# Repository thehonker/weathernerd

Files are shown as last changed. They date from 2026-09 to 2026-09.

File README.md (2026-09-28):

# WeatherNerd




Low-power, long-duration weather stations built around the [WindNerd Core](https://github.com/windnerd-labs/Windnerd-Core) anemometer and ESP32-C6 dataloggers.

## What is this?

Two station variants sharing the same wind sensor and datalogger platform:

### Remote Station (v1)

A battery-powered, 6-month-unattended weather station for remote deployment. No grid power, no WiFi infrastructure, no maintenance visits. Deploy in fall, retrieve in spring.

- **Wind:** WindNerd Core (STM32G031F8) with custom firmware — STOP mode sleep (~5 µA), woken on demand by ESP32-C6 every 5s via GPIO interrupt. Wind speed via rotor pulse counting, direction via TMAG5273 magnetic angle sensor.
- **Datalogger:** ESP32-C6 SuperMini, running **ESP-IDF v6.1** (not Arduino — the LP RISC-V coprocessor requires ESP-IDF's `ulp_embed_binary` build system). LP core handles the 5s wind sampling loop while the main core sleeps (~7 µA deep sleep). Main core wakes every 1 min for temp/RH/pressure, rain ADC, and SD card flush.
- **Sensors:** BME280 (temp/RH/pressure, I2C), DS3231 RTC (±2 ppm, I2C), DIY piezo disdrometer (ADC, rain rate).
- **Storage:** 8 GB industrial microSD via SPI. Two daily CSV files: `YYYY-MM-DD-wind.csv` (5s samples) and `YYYY-MM-DD-env.csv` (1 min samples). ~168 MB for 6 months.
- **Power:** 2× ER34615 Li-SOCl2 D-cells (38 Ah, -55°C rated). Total system draw ~0.55 mA (16× battery headroom over 6 months). Battery lasts years — power is a non-issue.
- **Uplink:** SIM7080G Cat-M1 modem on AT&T LTE-M network. MQTT uplink every 30 min with buffered data. Daily GPS fix via SIM7080G GNSS syncs the DS3231 RTC, eliminating long-term drift. PSM sleep (~3 µA module) between uploads.
- **Retrieval:** Press CON button on the enclosure → ESP32-C6 powers on OLED display + starts WiFi 6 soft-AP. Connect with phone/laptop, browse and download CSV files. Rotary encoder + OLED for on-device UI. LTE-M uplink provides live data during deployment — WiFi is for full bulk download on physical retrieval.
- **Antenna:** Directional Yagi (700–2700 MHz) aimed at nearest AT&T tower for LTE-M. Passive GNSS patch antenna (25×25mm) for daily GPS RTC sync.
- **Cost:** ~$214-283 total BOM.

### Home Station (future)

A wall-powered variant for permanent installation at home. Same WindNerd Core + ESP32-C6 platform, but always-on WiFi with Prometheus-style metrics exposure:

- `/metrics` endpoint scraped by a Prometheus instance
- Wind speed, direction, temperature, RH, pressure, rain rate as gauge metrics
- DS3231 RTC for timestamp accuracy
- No battery, no SD card — data lives in Prometheus
- OLED + encoder UI always available
- Optional: push to a remote station's data archive for cross-site comparison

Design docs for the home station will be added when we start that phase. The remote station firmware and hardware are the priority — the home station reuses the same components and most of the same firmware.

## Repo layout

```none
weathernerd/
├── README.md              ← you are here
├── LICENSE
├── .github/workflows/
│   └── build-windnerd-stm32g031f8.yml  ← CI/CD for STM32 firmware
└── local-storage/
    ├── notes/
    │   ├── hardware-design.md   ← pin allocation, wiring, BOM, component selection
    │   ├── power-budget.md      ← current draw analysis, battery sizing
    │   ├── storage-budget.md    ← data volume, SD card selection, file strategy
    │   └── lte-uplink.md        ← LTE-M modem options, antenna, SIM, power impact
    └── firmware/
        ├── windnerd-stm32g031f8/  ← custom WindNerd Core firmware (⚠️ WIP, untested)
        │   ├── README.md           ← firmware docs, build & flash instructions
        │   ├── build.sh            ← build locally (Docker)
        │   ├── flash.sh            ← flash via ST-Link (Docker)
        │   ├── src/src.ino         ← firmware source
        │   ├── lib/Windnerd-Core/  ← git submodule
        │   └── build-env/          ← Dockerfile + compile/flash scripts
        └── esp32c6-supermini/     ← ESP32-C6 datalogger firmware (ESP-IDF, ✅ compiles)
            ├── README.md           ← firmware docs, build & flash instructions
            ├── CMakeLists.txt      ← ESP-IDF project root
            ├── sdkconfig.defaults  ← LP core, FAT/SD, WiFi AP, BT disabled
            ├── partitions.csv      ← nvs + phy + 3 MB factory
            ├── build.sh            ← build locally (Docker)
            ├── flash.sh            ← flash via USB serial (Docker)
            ├── main/
            │   ├── CMakeLists.txt  ← ulp_embed_binary() for LP core
            │   ├── main.c          ← main core firmware
            │   ├── storage.h/.c    ← SDSPI + CSV writing (wind + env)
            │   ├── i2c_bus.h/.c    ← shared I2C bus (GPIO6/7)
            │   ├── ds3231.h/.c     ← DS3231 RTC driver
            │   ├── bme280.h/.c     ← BME280 driver + compensation
            │   ├── wifi.h/.c         ← WiFi AP + HTTP server (files, clock, format, reboot, halt)
            │   ├── oled.h/.c       ← SH1106 OLED driver (128×64, text)
            │   ├── oled_font.h     ← 8×8 ASCII font
            │   ├── input.h/.c      ← EC11 encoder + CON/BAK/PSH buttons
            │   ├── ui.h/.c         ← Interactive menu UI (6 items)
            │   └── lp_core/main.c  ← LP core firmware
            └── build-env/          ← Dockerfile (espressif/idf:release-v6.1)
```

## Design docs

Start with [hardware-design.md](local-storage/notes/hardware-design.md) for the full system overview, pin allocation, and BOM.
[power-budget.md](local-storage/notes/power-budget.md) covers current draw and battery life.
[storage-budget.md](local-storage/notes/storage-budget.md) covers data volumes and SD card selection.
[lte-uplink.md](local-storage/notes/lte-uplink.md) covers LTE-M modem selection, antenna, SIM, and power budget impact.

## Firmware

### WindNerd Core (STM32G031F8) — ⚠️ WIP, untested - compiles, sensors implemented

Custom firmware replacing the factory WindNerd Core firmware. Drops power from ~0.6 mA (SLEEP mode) to ~0.04 mA (STOP mode) by sleeping until the ESP32-C6 triggers a read via GPIO interrupt. Uses the TMAG5273 driver directly from the WindNerd Core library — the `WN_Core` class is not used.

- **Status:** Written, compiles clean (62% flash, 25% RAM), not yet tested on hardware
- **Build:** `./build.sh` (Docker, no host tooling needed) → `build/src.ino.bin`
- **Flash:** `./flash.sh` (ST-Link V2, openocd in Docker) or `./flash.sh --ci` (download from GitHub releases)
- **CI/CD:** Auto-builds on push to main, publishes env image to GHCR + GitHub release with firmware binaries
- **Details:** [windnerd-stm32g031f8/README.md](local-storage/firmware/windnerd-stm32g031f8/README.md)

### ESP32-C6 SuperMini — ⚠️ WIP, untested — compiles, all features implemented

ESP32-C6 datalogger firmware built with **ESP-IDF v6.1**. The LP RISC-V coprocessor handles the 5s wind sampling loop (WindNerd trigger + UART RX) while the main core sleeps. Main core wakes every 1 min for sensors + SD card flush. Interactive UI (OLED + encoder + buttons) triggered by CON button press — provides live data, file browser, WiFi portal, clock sync, format SD, reboot, sleep, and halt.

- **Status:** All firmware modules written and compiling clean. Full data flow implemented: LP core samples wind every 5s → main core flushes to SD every 1 min. Interactive UI with 8 menu items. WiFi portal with file browser, clock sync, format SD, reboot, halt. Only hardware testing remains.
- **Binary:** 1.15 MB (37% of 3 MB factory partition — WiFi stack adds ~800 KB)
- **Build:** `./build.sh` (Docker, no host toolchain needed) → `build/esp32c6_weathernerd.bin`
- **Flash:** `./flash.sh` (USB serial, esptool in Docker) or `./flash.sh --ci` (download from GitHub releases)
- **CI/CD:** Auto-builds on push, publishes env image to GHCR + GitHub release with firmware binaries
- **Details:** [esp32c6-supermini/README.md](local-storage/firmware/esp32c6-supermini/README.md)

**Why ESP-IDF, not Arduino?** The ESP32-C6's LP RISC-V coprocessor is the whole reason we chose the C6 over the C3. Arduino-esp32 does not support LP core programming — no `ulp_embed_binary()` build pipeline, no LP core API exposure. ESP-IDF is the official framework for LP core development.

## Key design decisions

- **WindNerd custom firmware** — factory firmware draws 0.6 mA. Custom STOP mode + on-demand sampling drops it to ~0.04 mA. 7× total system power reduction.
- **ESP32-C6 over ESP32-C3** — the C6's LP RISC-V coprocessor handles the 5s sampling loop while the main core sleeps. The C3 has no LP core, so the main core would wake every 5s, roughly doubling power consumption. This required switching from Arduino to ESP-IDF — Arduino-esp32 doesn't support LP core programming.
- **No solar** — at 0.55 mA average, the battery alone has 16× headroom over 6 months. Solar adds complexity and failure modes for zero benefit.
- **Two data streams** — wind+rain at 5s (LP core) and temp/RH/pressure at 1 min (main core). Separate daily CSV files. Temp changes slowly; 1 min is plenty.
- **CON button + OLED** — the station sleeps with zero UI. A momentary button (CON) wakes the main core via GPIO interrupt, firmware powers on the OLED via MOSFET (GPIO5), and starts a WiFi AP for data retrieval. Zero power when off. BAK button at top-level menu returns to low-power mode. 60s inactivity timeout as backup. A future "Halt" option (full system stop, power cycle to resume) may be added to both the OLED menu and WiFi portal.
- **SPI over SDIO for SD card** — GPIO18–23 are the ESP32-C6's native SDIO peripheral, but 4-bit SDIO needs 6 pins and would eat GPIO20/21 (encoder) and GPIO22/23 (CON/BAK buttons). SPI mode uses 4 pins and the data rate is trivial (~838 KB/day, 70-byte appends once per minute). The SD card is asleep 55s out of every 60s — SDIO's speed advantage is irrelevant. The saved pins keep the encoder and buttons on safe, non-strapping GPIO.
- **DIY piezo disdrometer** — no moving parts, $2 in parts, logs raw ADC peaks. Calibrate later against a reference gauge. v1 has no op-amp (simplest); v2 adds OPA376 if drizzle sensitivity is needed.
- **SIM7080G LTE-M uplink** — Cat-M1 on AT&T (the only carrier with coverage at the deployment site). PSM sleep at ~3 µA between 30-min MQTT uploads. LC filter on VBAT handles Cat-M1 TX spikes from the high-internal-resistance Li-SOCl2 battery. Daily GPS fix via the modem's GNSS receiver syncs the DS3231 RTC, eliminating ±5 min drift over 6 months. NB-IoT is dead on AT&T (sunset Q1 2025) — Cat-M1 is the only viable low-power IoT option.

## License

`AGPL-3.0-or-later`. See [LICENSE](LICENSE).

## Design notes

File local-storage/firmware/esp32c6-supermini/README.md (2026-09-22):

# esp32c6-supermini — WeatherNerd ESP32-C6 Firmware



Firmware for the ESP32-C6 SuperMini datalogger — the main controller of the WeatherNerd remote station.

Built with **ESP-IDF v6.1** (not Arduino). The ESP32-C6's LP RISC-V coprocessor requires ESP-IDF's `ulp_embed_binary` build system — Arduino-esp32 does not support LP core programming.

## Architecture

```
┌─────────────────────────────────────────────────┐
│  ESP32-C6 SuperMini                              │
│                                                  │
│  ┌──────────┐   shared RTC    ┌──────────────┐   │
│  │ LP Core  │───memory───────▶│  Main Core   │   │
│  │ (RISC-V) │                 │  (RISC-V)    │   │
│  │          │                 │              │   │
│  │ 5s loop: │                 │ 1 min wake:  │   │
│  │ trigger  │                 │ read BME280  │   │
│  │ WindNerd │                 │ read DS3231  │   │
│  │ read UART │                │ read rain ADC │   │
│  │ store    │                 │ flush to SD   │   │
│  │ sample   │                 │ deep sleep    │   │
│  │ halt     │                 │              │   │
│  └──────────┘                 └──────────────┘   │
│       │                              │           │
│       │ GPIO1 (trigger)              │ GPIO22    │
│       │ GPIO4 (LP_UART RX)           │ (WiFi SW) │
│       ▼                              ▼           │
│  ┌──────────┐                 ┌──────────────┐   │
│  │ WindNerd │                 │ WiFi AP +    │   │
│  │ Core     │                 │ OLED UI      │   │
│  │ (STM32)  │                 │ (on demand)  │   │
│  └──────────┘                 └──────────────┘   │
└─────────────────────────────────────────────────┘
```

### LP Core (ULP coprocessor)

Wakes every 5 seconds via LP timer while main core sleeps:
1. Pulse GPIO1 high for 10ms → wakes WindNerd Core (STM32G031F8) from STOP mode
2. Read UART response on LP_UART (GPIO4, 9600 baud) — `WNI,<speed>,<dir>\n`
3. Parse and store wind sample in shared RTC memory buffer
4. After 12 samples (1 minute), wake the main core
5. Halt — LP timer wakes again in 5s

### Main Core

**Cold boot:** Initialize LP UART (9600 baud, RX=GPIO4), load LP core binary, configure GPIO22 wakeup, enter deep sleep.

**LP core wakeup (every 1 min):** Read BME280 (temp/RH/pressure, I2C), read DS3231 (timestamp, I2C), read rain ADC (HP ADC, GPIO0), flush 12 wind samples + env data to SD card (SPI), enter deep sleep.

**GPIO22 wakeup (CON button):** Power on OLED via MOSFET (GPIO5), start WiFi 6 soft-AP, serve CSV files via HTTP, OLED + rotary encoder UI. Returns to low-power mode on 60s timeout, menu action, or BAK button at top level.

### Known limitation: rain ADC resolution

The ESP32-C6 LP core does **not** have an LP ADC peripheral (`SOC_LP_ADC_SUPPORTED` is not defined). Rain ADC sampling moved to the main core's 1-minute wake cycle using the HP ADC. Rain resolution is 1 min instead of 5s — acceptable for v1 since rain rate doesn't change much in 60 seconds.

## Project structure

```
esp32c6-supermini/
├── CMakeLists.txt           ← ESP-IDF project root
├── sdkconfig.defaults       ← LP core, FAT/SD, WiFi AP enabled, BT disabled, 4 MB flash
├── partitions.csv           ← nvs (16K) + phy (4K) + factory (3 MB)
├── build.sh                 ← Docker build helper
├── flash.sh                 ← Docker flash helper (--ci mode)
├── .gitignore
├── main/
│   ├── CMakeLists.txt       ← idf_component_register + ulp_embed_binary()
│   ├── main.c               ← main core firmware (deep sleep, wakeup dispatch)
│   ├── storage.h / .c       ← SDSPI init, FAT mount, CSV file writing (wind + env)
│   ├── i2c_bus.h / .c       ← shared I2C bus (GPIO6/7, 100 kHz)
│   ├── ds3231.h / .c        ← DS3231 RTC driver (probe, get/set time, temp)
│   ├── bme280.h / .c        ← BME280 driver (probe, init, forced read, compensation)
│   ├── wifi.h / .c           ← WiFi soft-AP + HTTP server (files, clock sync, format, reboot, halt)
│   ├── oled.h / .c          ← SH1106 OLED driver (I2C, 128×64, text rendering)
│   ├── oled_font.h          ← 8×8 ASCII font (96 chars, 768 bytes)
│   ├── input.h / .c         ← EC11 encoder + CON/BAK/PSH buttons (GPIO ISR + debounce)
│   ├── ui.h / .c            ← Interactive menu UI (live data, files, WiFi, clock, sleep, halt)
│   └── lp_core/
│       └── main.c           ← LP core firmware (5s wind sampling loop)
└── build-env/
    ├── Dockerfile           ← espressif/idf:release-v6.1 base
    ├── compile.sh           ← container: idf.py set-target + build
    └── flash.sh             ← container: idf.py flash
```

## Hardware

- **Board:** ESP32-C6 SuperMini (ESP32-C6FH4)
- **Flash:** 4 MB QIO
- **LP core peripherals used:** LP IO (GPIO1 trigger), LP UART (GPIO4 RX, 9600 baud)
- **Main core peripherals:** I2C (BME280 + DS3231 + OLED on GPIO6/GPIO7), SPI (microSD on GPIO2/3/18/19), ADC (GPIO0 rain), GPIO5 (OLED MOSFET gate), GPIO14/20/21 (encoder TRA/TRB/PSH), GPIO22 (CON button), GPIO23 (BAK button)

See [hardware-design.md](../../notes/hardware-design.md) for full pin allocation and wiring.

## Dependencies

- **ESP-IDF v6.1** (bundled in Docker image — no host install needed)
- Docker (for containerized build/flash)
- USB-C cable (for flashing)

## Building locally

### Compile

```bash
cd local-storage/firmware/esp32c6-supermini
./build.sh
```

Pulls the prebuilt env image from GHCR and compiles the firmware. Output:

```
build/esp32c6_weathernerd.bin            ← flashable application binary
build/esp32c6_weathernerd.elf            ← debug symbols
build/bootloader/bootloader.bin          ← ESP32-C6 bootloader
build/partition_table/partition-table.bin ← partition table
```

To use a locally built image instead of GHCR:

```bash
docker build -t esp32c6-build ./build-env
ESP32C6_BUILD_IMAGE=esp32c6-build ./build.sh
```

### Flash

Connect ESP32-C6 SuperMini via USB-C, then:

```bash
./flash.sh                # flash locally built binary
./flash.sh --ci           # download latest CI release and flash that
./flash.sh --ci <sha>     # download release for a specific commit and flash
```

Override the serial port if auto-detection fails:

```bash
ESP32_PORT=/dev/ttyACM1 ./flash.sh
```

## CI/CD

GitHub Actions workflow: [`.github/workflows/build-esp32c6-supermini.yml`](../../../.github/workflows/build-esp32c6-supermini.yml)

**Triggers:** push to `main` or PR touching `local-storage/firmware/esp32c6-supermini/**`, plus manual dispatch.

**What it does:**
1. Builds the Docker env image and pushes it to `ghcr.io/thehonker/weathnerd-esp32c6-supermini-env` (tagged `:latest` and `:sha`). Image push happens only on push to `main`.
2. Compiles the firmware using the image (`idf.py set-target esp32c6 && idf.py build`).
3. Uploads `esp32c6_weathernerd.bin`, `esp32c6_weathernerd.elf`, `bootloader.bin`, and `partition-table.bin` as workflow artifacts (90-day retention).
4. On push to `main`: creates a GitHub release tagged `esp32c6-supermini-<sha>` with the binaries as downloadable assets.

**Env image:** `ghcr.io/thehonker/weathnerd-esp32c6-supermini-env:latest` — based on `espressif/idf:release-v6.1` (ESP-IDF v6.1 + RISC-V toolchain + esptool). Reusable for local builds:

```bash
docker pull ghcr.io/thehonker/weathnerd-esp32c6-supermini-env:latest
docker run --rm -v "$(pwd):/project" -w /project -u $(id -u) -e HOME=/tmp \
  ghcr.io/thehonker/weathnerd-esp32c6-supermini-env:latest /usr/local/bin/compile.sh
```

## Implementation status

| Component | Status |
|---|---|
| ESP-IDF project + LP core build | ✅ Compiles clean |
| LP core: WindNerd trigger (GPIO1) | ✅ Written |
| LP core: UART RX + parse | ✅ Written |
| LP core: sample buffer + main wakeup | ✅ Written |
| Main core: deep sleep + wakeup dispatch | ✅ Written |
| Main core: LP UART init | ✅ Written |
| Main core: I2C bus (shared) | ✅ Written |
| Main core: DS3231 RTC (I2C) | ✅ Written |
| Main core: BME280 sensor (I2C) | ✅ Written |
| Main core: rain ADC reads (HP ADC) | ✅ Written |
| Main core: SD card logging (SPI) | ✅ Written |
| Main core: env CSV writing (temp/RH/press) | ✅ Written |
| WiFi retrieval mode (soft-AP + HTTP) | ✅ Written |
| Clock sync from browser | ✅ Written |
| File browser + download | ✅ Written |
| OLED driver (SH1106, I2C) | ✅ Written |
| Encoder + button input (GPIO ISR) | ✅ Written |
| Interactive menu UI (6 items) | ✅ Written |
| OLED power gating (MOSFET on GPIO5) | ✅ Written |
| Halt option (full system stop) | ✅ Written |
| Wind samples → SD card (ulp_ variable access) | ✅ Written |

## Why ESP-IDF, not Arduino?

The ESP32-C6's LP RISC-V coprocessor is the whole reason we chose the C6 over the C3. Arduino-esp32 (3.3.12) does not support LP core programming — there's no build pipeline for `ulp_embed_binary()`, no `ulp_lp_core_load_binary()` / `ulp_lp_core_run()` API exposure, and no Kconfig support for `CONFIG_ULP_COPROC_TYPE_LP_CORE`. The feature has been requested ([arduino-esp32#9721](https://github.com/espressif/arduino-esp32/issues/9721)) since May 2024 with no progress.

ESP-IDF is the official framework for LP core development. The build system (`ulp_embed_binary` / `ulp_add_project`), Kconfig options, and LP core APIs (`ulp_lp_core.h`, `ulp_lp_core_uart.h`, `ulp_lp_core_gpio.h`) are all first-class. The Docker build pattern still works — just `espressif/idf:release-v6.1` instead of arduino-cli.

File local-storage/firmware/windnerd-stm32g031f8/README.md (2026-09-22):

# windnerd-stm32g031f8 — Custom WindNerd Core Firmware



Custom firmware for the [WindNerd Core](https://github.com/windnerd-labs/Windnerd-Core) board (STM32G031F8Px), replacing the factory firmware for ESP32-C6 triggered on-demand sampling.

## Why custom firmware?

The factory firmware is designed for standalone operation — it runs a 10 Hz timer (TIM3) that drives 3-second sampling windows, outputs `WNI`/`WNA` messages on UART, and enters SLEEP mode between samples. Current draw: ~0.6 mA in low power mode.

Our station doesn't need continuous sampling. The ESP32-C6 LP core triggers a read every 5 seconds. Between triggers, the WindNerd Core has nothing to do. STOP mode (~5 µA) drops power consumption by 120× — from 0.6 mA to 0.04 mA.

| | Factory firmware | This firmware |
|---|---|---|
| Sleep mode | SLEEP (~0.6 mA) | STOP (~5 µA) |
| Sampling trigger | TIM3 timer (10 Hz) | ESP32-C6 GPIO (EXTI) |
| Sample interval | 3 s (fixed) | 5 s (configurable, set by ESP32-C6) |
| Output | `WNI` + `WNA` messages | `WNI` only (on demand) |
| TMAG5273 | Read every 100-500 ms | Read only on trigger |
| LEDs | Active (speed + north) | Off (not initialized) |
| Power | ~0.6 mA | ~0.04 mA (estimated) |

## How it works

```
                    ESP32-C6 GPIO1 (trigger)
                           │ RISING edge
                           ▼
    ┌─────────────────────────────────────┐
    │  STM32G031F8 in STOP mode (~5 µA)   │
    │                                     │
    │  EXTI wakes CPU                     │
    │  → restore 8 MHz clock              │
    │  → read pulse count (reset to 0)    │
    │  → read TMAG5273 angle (I2C)        │
    │  → compute speed = pulses × 1.31 / 5│
    │  → UART TX2: "WNI,<speed>,<dir>\n"   │
    │  → return to STOP mode              │
    └─────────────────────────────────────┘
```

Rotor pulses (reed switch) increment a counter via EXTI. This works in STOP mode — the EXTI interrupt briefly wakes the CPU, the ISR increments the counter, and the CPU returns to STOP. The ESP32-C6 doesn't need to know about individual pulses; it just triggers every 5 seconds and gets the accumulated count.

## Output format

```
WNI,<speed_mps>,<direction_deg>
```

- `speed_mps`: wind speed in m/s, one decimal place (e.g. `3.2`)
- `direction_deg`: wind direction 0–359 degrees, or `0` if TMAG5273 read failed

Example: `WNI,3.2,247`

Same `WNI` format as factory firmware. No `WNA` (averaged) messages — averaging is done on the ESP32-C6 side from the 5s samples.

## Dependencies

- [WindNerd Core library](https://github.com/windnerd-labs/Windnerd-Core) — only for `Windnerd_TMAG5273.h/.cpp` and `Windnerd_I2C.h/.cpp` (TMAG5273 driver + I2C wrapper). The `WN_Core` class is **not** used. Included as a git submodule at `lib/Windnerd-Core/`.
- [stm32duino](https://github.com/stm32duino) 3.0.0 board package
- Docker (for containerized build/flash)

## Building locally

### Prerequisites

- Docker installed and running
- ST-Link V2 dongle (for flashing)
- Clone with submodules:

```bash
git clone --recursive <repo-url>
# or if already cloned:
git submodule update --init
```

### Compile

```bash
cd local-storage/firmware/windnerd-stm32g031f8
./build.sh
```

This pulls the prebuilt env image from GHCR and compiles the firmware. Output:

```
build/src.ino.bin   ← flashable binary (ST-Link SWD)
build/src.ino.elf    ← debug symbols
```

To use a locally built image instead of the GHCR one:

```bash
docker build -t windnerd-build ./build-env
WINDNERD_BUILD_IMAGE=windnerd-build ./build.sh
```

### Flash

Connect ST-Link V2 (CLK, DIO, RST, GND) to the WindNerd Core board, then:

```bash
./flash.sh                # flash locally built binary
./flash.sh --ci           # download latest CI release and flash that
./flash.sh --ci <sha>     # download release for a specific commit and flash
```

This passes USB through to the container, which runs openocd to flash via ST-Link SWD. No host-side tooling required — openocd is baked into the Docker image. The `--ci` mode downloads prebuilt firmware from GitHub releases using `curl` (no `gh` CLI needed).

Same `WINDNERD_BUILD_IMAGE` override works for `flash.sh`.

### Build without Docker (Arduino IDE)

If you prefer the Arduino IDE:

1. Follow the [WindNerd Core programming guide](https://github.com/windnerd-labs/Windnerd-Core/blob/main/docs/PROGRAM.md) to install STM32CubeProgrammer and stm32duino.
2. Install the WindNerd Core library into your Arduino `libraries/` folder (symlink or copy from `lib/Windnerd-Core/`).
3. Open `src/src.ino` in Arduino IDE.
4. Board: **Generic STM32G031F8Px**
5. Upload method: **STM32CubeProgrammer (SWD)** via ST-Link V2
6. Upload

## Pin assignments

| Pin | Function | Notes |
|---|---|---|
| PA25 | Rotor pulse input | Reed switch, EXTI RISING |
| PA22 | I2C SCL | TMAG5273 |
| PA23 | I2C SDA | TMAG5273 |
| PA0 | ESP32-C6 trigger | EXTI RISING, INPUT_PULLDOWN, expansion header |
| USART2 TX2 | UART output | 9600 baud, expansion header, to ESP32-C6 GPIO4 |

**Expansion header pinout:**

```
VCC
GND
PA6
PA5
PA4
PA3
TX2  (USART2 TX — UART output to ESP32-C6)
PA1
PA0  (ESP32-C6 trigger input)
3V3
TX   (bootloader)
RX   (bootloader)
GND
```

PA0 is confirmed on the header. If PA0 is needed for something else, PA1/PA3/PA4/PA5/PA6 are also available — all are EXTI-capable. Update `TRIGGER_PIN` in `src/src.ino`.

## Configuration

All configuration is in `src/src.ino`:

| Constant | Default | Description |
|---|---|---|
| `SAMPLE_INTERVAL_SEC` | 5 | Seconds between ESP32-C6 triggers. Must match ESP32-C6 LP core loop. |
| `HZ_TO_MS` | 1.31 | Rotor calibration. Standard WindNerd rotor = 1.31 m/s per Hz. |
| `UART_BAUD` | 9600 | Must match ESP32-C6 UART RX config. |

If the ESP32-C6 sample interval changes, update `SAMPLE_INTERVAL_SEC` and reflash. The STM32 uses this constant for speed calculation since `millis()`/`micros()` are unreliable after STOP mode (SysTick stops).

## STOP mode notes

- **SRAM retained** — `pulse_count` and all variables survive STOP mode
- **SysTick stopped** — `millis()` and `micros()` don't work after wakeup until `SystemClock_Config()` restores the clock
- **TIM3 stopped** — we don't use the WindNerd Core's timer-driven sampling
- **EXTI works** — rotor pulse ISR and trigger ISR both fire in STOP mode
- **I2C works after wakeup** — TMAG5273 read happens after clock restore
- **Clock restore** — STOP mode resets SYSCLK to HSI 16 MHz; `SystemClock_Config()` restores 8 MHz (HSI/2)

## Power estimate

| State | Current | Duration | Per-5s avg |
|---|---|---|---|
| STOP mode | ~5 µA | ~4.99 s | 4.99 µA |
| Wake + read + UART | ~3 mA | ~10 ms | 6 µA |
| **Average** | | | **~11 µA (~0.011 mA)** |

Factory firmware low power mode: ~600 µA. This firmware: ~11 µA. **55× reduction.**

Actual current needs to be measured on the physical board. The TMAG5273 sleep current (<1 µA) and I2C bus pull-ups may add a few µA.

## CI/CD

GitHub Actions workflow: [`.github/workflows/build-windnerd-stm32g031f8.yml`](../../../.github/workflows/build-windnerd-stm32g031f8.yml)

**Triggers:** push to `main` or PR touching `local-storage/firmware/windnerd-stm32g031f8/**`, plus manual dispatch.

**What it does:**
1. Builds the Docker env image and pushes it to `ghcr.io/thehonker/weathnerd-windnerd-stm32g031f8-env` (tagged `:latest` and `:sha`). Image push happens only on push to `main`.
2. Compiles the firmware using the image.
3. Uploads `src.ino.bin` and `src.ino.elf` as workflow artifacts (90-day retention).
4. On push to `main`: creates a GitHub release tagged `windnerd-stm32g031f8-<sha>` with the `.bin` and `.elf` as downloadable assets.

On PRs, the image builds but isn't pushed — firmware still compiles and artifacts are available for review. On `main`, the env image, workflow artifacts, and a GitHub release are all published.

**Env image:** `ghcr.io/thehonker/weathnerd-windnerd-stm32g031f8-env:latest` — Ubuntu 24.04 + arduino-cli 1.5.1 + stm32duino 3.0.0 + openocd. Reusable for local builds if you don't want to build the image yourself:

```bash
docker pull ghcr.io/thehonker/weathnerd-windnerd-stm32g031f8-env:latest
docker run --rm -v "$(pwd):/firmware" ghcr.io/thehonker/weathnerd-windnerd-stm32g031f8-env:latest /usr/local/bin/compile.sh
```

**Releases:** Firmware binaries are published as GitHub releases at `https://github.com/thehonker/weathernerd/releases`. Download with `curl` or use `./flash.sh --ci`.

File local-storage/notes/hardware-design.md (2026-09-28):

# Remote Wind Monitoring Station — Hardware Design

**Date:** 2026-09-22
**Author:** Coilette (for goos)
**Status:** Draft
**Related:** [power-budget.md](power-budget.md), [storage-budget.md](storage-budget.md)

---

## System Overview

```
  2× ER34615 Li-SOCl2 D-cell (3.6V, 38 Ah total)
       │
       ├──────────────────────────┐ (raw 3.6V)
       │                          │
  ┌────┴─────┐               SIM7080G VBAT
  │ HT7333   │ 3.3V LDO      (LTE-M modem, bulk cap for TX)
  └────┬─────┘ (~1 µA Iq)
       │ 3.3V rail
  ┌────┼──────┬───────┬───────┬───────┬───────┬───────┐
  ▼    ▼      ▼       ▼       ▼       ▼       ▼       ▼
WindNerd ESP32  BME280 DS3231 SD card Piezo  SIM7080G OLED
 Core    C6                            rain   (VCC)   (via
(STM32G0)                                (ADC)         MOSFET)
  │      │
  │      ├─ GPIO1  → trigger → WindNerd
  │      ├─ GPIO4  ← UART RX  ← WindNerd TX2 (9600 baud)
  │      ├─ GPIO0  ← ADC      ← Piezo rain
  │      ├─ GPIO6/7 → I2C → BME280 (0x76) + DS3231 (0x68) + OLED (0x3C) + MCP23008 (0x20)
  │      ├─ GPIO2/3/18/19 → SPI → SD card
  │      ├─ GPIO14 ← MCP23008 INT (encoder + buttons via I2C expander)
  │      ├─ GPIO5  → MOSFET gate → OLED VCC (power gate, firmware-controlled)
  │      ├─ GPIO16/17 → UART0 → SIM7080G (LTE-M uplink)
  │      ├─ GPIO15 → DTR → SIM7080G (PSM sleep/wake control)
  │      ├─ GPIO9  → PWR → SIM7080G (power key, pulse to on/off)
  │      ├─ GPIO20/22/23 → FREE (spare GPIO)
  │      └─ WiFi 6 soft-AP → phone/laptop (data retrieval)
```

**LP core** (5s loop): trigger WindNerd → read UART → buffer in RTC memory
**Main core** (1 min wake): read BME280 + DS3231 + rain ADC → flush buffered data to SD → return to deep sleep
**Main core** (30 min wake): wake SIM7080G from PSM via DTR → MQTT upload buffered data → modem back to PSM → deep sleep
**Main core** (daily): wake SIM7080G → enable GNSS → GPS fix → sync DS3231 RTC → disable GNSS → modem back to PSM → deep sleep
**On demand** (CON button press via MCP23008): wake main core → power on OLED via MOSFET → start WiFi AP → serve CSV files + clock sync → return to low-power mode on timeout or menu action

---

## Netlist

Every net on the platform. Sorted by signal name.

| Net | From | To | Notes |
|-----|---|----|---|
| **3V3** | HT7333 OUT | ESP32-C6 3V3, BME280 VCC, DS3231 VCC, SD VCC, OLED VCC (via Q2), WindNerd VCC, piezo GND ref | Main 3.3V rail |
| **GND** | HT7333 GND | ESP32-C6 GND, BME280 GND, DS3231 GND, SD GND, OLED GND, WindNerd GND, piezo GND, Q1 source, Q2 source, R2 bottom | Common ground |
| **VBAT** | ER34615 + (2 cells parallel) | HT7333 IN | 3.6V nominal, 19 Ah per cell, 38 Ah total |
| **VBAT_GND** | ER34615 − | HT7333 GND | |
| **WIND_TX** | WindNerd TX2 (yellow wire) | ESP32-C6 GPIO4 (LP_UART_RXD) | 9600 baud, 10kΩ pull-up on GPIO4 |
| **WIND_TRIG** | ESP32-C6 GPIO1 (LP core) | WindNerd trigger input | LP core toggles every 5s to wake WindNerd |
| **I2C_SDA** | ESP32-C6 GPIO6 | BME280 SDA, DS3231 SDA, OLED SDA | Shared bus, 0x76 + 0x68 + 0x3C |
| **I2C_SCL** | ESP32-C6 GPIO7 | BME280 SCL, DS3231 SCL, OLED SCL | Shared bus |
| **SPI_SCK** | ESP32-C6 GPIO2 | SD SCK | 10kΩ pull-down (idle low) |
| **SPI_CS** | ESP32-C6 GPIO3 | SD CS | 10kΩ pull-up (idle high) |
| **SPI_MOSI** | ESP32-C6 GPIO18 | SD MOSI | |
| **SPI_MISO** | ESP32-C6 GPIO19 | SD MISO | |
| **RAIN_ADC** | Piezo peak-hold C2 (+) | ESP32-C6 GPIO0 (ADC1_CH0) | Via 10kΩ series resistor R1 |
| **RAIN_RST** | ESP32-C6 GPIO8 | Q1 (2N7002) gate | HIGH 5ms pulse discharges C2. 10kΩ pulldown R2 to GND. |
| **OLED_PWR** | Q2 (AO3401) drain | OLED VCC | P-channel MOSFET switches VCC to OLED |
| **OLED_GATE** | ESP32-C6 GPIO5 | Q2 (AO3401) gate | LOW = OLED on, HIGH = OLED off. 10kΩ pull-up to 3V3. |
| **ENC_A** | EC11 encoder A | MCP23008 GP0 | Rotary encoder clock phase A (via I2C expander) |
| **ENC_B** | EC11 encoder B | MCP23008 GP1 | Rotary encoder data phase B (via I2C expander) |
| **ENC_PSH** | EC11 encoder push | MCP23008 GP2 | Encoder push button, internal pull-up (via I2C expander) |
| **CON_BTN** | CON button → GND | MCP23008 GP3 | Momentary, internal pull-up. UI confirm. INT wakes ESP32 on falling edge. |
| **BAK_BTN** | BAK button → GND | MCP23008 GP4 | Momentary, internal pull-up. UI back / enter sleep. (via I2C expander) |
| **EXP_INT** | MCP23008 INT | ESP32-C6 GPIO14 | Interrupt from I2C expander — wakes ESP32 on any pin change |
| **I2C_SDA** | ESP32-C6 GPIO6 | BME280 SDA, DS3231 SDA, OLED SDA, MCP23008 SDA | Shared bus, 0x76 + 0x68 + 0x3C + 0x20 |
| **I2C_SCL** | ESP32-C6 GPIO7 | BME280 SCL, DS3231 SCL, OLED SCL, MCP23008 SCL | Shared bus |
| **PIEZO+** | Piezo disc + terminal | D1 (1N4148) anode | AC signal from raindrop impacts |
| **PIEZO−** | Piezo disc − terminal | GND | |
| **CPUMP** | D1 cathode | C1 (1nF) top, D2 anode | Voltage doubler midpoint |
| **PEAK** | D2 cathode | C2 (470nF film) top, R1 (10kΩ) → GPIO0 | Peak-hold node — highest impact voltage |
| **CR1220+** | DS3231 BAT+ | CR1220 coin cell + | RTC backup battery |
| **CR1220−** | DS3231 BAT− | CR1220 coin cell − | |
| **SWD_CLK** | ST-Link CLK | WindNerd SWD CLK | Programming only |
| **SWD_DIO** | ST-Link DIO | WindNerd SWD DIO | Programming only |
| **SWD_RST** | ST-Link RST | WindNerd RST | Programming only |
| **SWD_GND** | ST-Link GND | WindNerd GND | Programming only |
| **USB_DP** | ESP32-C6 GPIO12 | USB-C D+ | Native USB programming. Do not use for anything else. |
| **USB_DM** | ESP32-C6 GPIO13 | USB-C D− | Native USB programming. Do not use for anything else. |
| **MODEM_VBAT** | ER34615 + (before LDO) | SIM7080G VBAT (via L1 inductor + C1–C6 bulk/bypass) | Raw battery 3.6V, modem main power. LC filter handles Cat-M1 TX spikes. |
| **MODEM_VCC** | HT7333 OUT (3.3V) | SIM7080G VCC | Logic level reference, 3.3V from LDO rail |
| **MODEM_RXD** | ESP32-C6 GPIO16 (UART0 TX) | SIM7080G RXD | ESP32 TX → modem RX. UART0, 115200 baud. |
| **MODEM_TXD** | SIM7080G TXD | ESP32-C6 GPIO17 (UART0 RX) | Modem TX → ESP32 RX. UART0, 115200 baud. |
| **MODEM_DTR** | ESP32-C6 GPIO15 | SIM7080G DTR | PSM sleep/wake control. HIGH = modem sleeps (PSM), LOW = modem awake. |
| **MODEM_PWR** | ESP32-C6 GPIO9 | SIM7080G PWR | Power key. Pulse LOW ≥1s to power on, pulse LOW ≥1s to power off. |

### Power tree

```
VBAT (3.6V, 38Ah)
  ├─ [L1 1µH] ─ [C1-C6 300µF cap bank] ─ SIM7080G VBAT (LC filter for TX spikes)
  └─ HT7333 LDO (3.3V, ~1µA Iq)
       ├─ ESP32-C6 SuperMini (3V3 pin)
       ├─ WindNerd Core (VCC)
       ├─ BME280 (VCC)
       ├─ DS3231 (VCC)
       ├─ SD card (VCC)
       ├─ SIM7080G VCC (logic level reference, 3.3V)
       ├─ Q2 AO3401 source → OLED VCC (when gated on)
       └─ Piezo circuit (GND reference only — no DC power)
```

---

## Components

### 1. WindNerd Core (wind sensor + MCU)

- **MCU:** STM32G031F8Px (Cortex-M0+, 32KB flash, 8KB RAM)
- **Sensors:** Rotor pulse counting (speed) + TMAG5273 magnetic angle (direction)
- **Output:** USART2 @ 9600 baud, TX2 pin (yellow wire)
- **Input:** GPIO interrupt (our trigger pin)
- **Power:** 3.3V or 5V (onboard regulator accepts either)
- **Programming:** ST-Link V2 (SWD: CLK, DIO, RST, GND) or serial bootloader
- **Current:** ~0.04 mA (custom firmware, STOP mode, on-demand)
- **Source:** [windnerd.net](https://windnerd.net/en/shop) — kit includes board, magnets, bearings
- **3D files:** [windnerd-labs/Anemometer-3D-files](https://github.com/windnerd-labs/Anemometer-3D-files)

### 2. ESP32-C6 SuperMini (datalogger)

- **MCU:** ESP32-C6 (RISC-V single core, 160MHz, LP RISC-V coprocessor)
- **Flash:** 4 MB
- **WiFi:** WiFi 6 (802.11ax)
- **BLE:** BLE 5.3
- **Deep sleep:** ~7 µA (with LP core active)
- **GPIO:** 22 broken out (silkscreen 0–9, 12–15, 16/TX, 17/RX, 18–23) on SuperMini form factor
- **Power:** 3.3V (onboard 3.3V LDO accepts 5V via USB or 3.3V direct)
- **Programming:** USB-C (native USB, no UART adapter needed)

### 3. BME280 (temp / RH / pressure)

- **Interface:** I2C (address 0x76 or 0x77 depending on breakout)
- **Power:** 3.3V
- **Current:** 3.6 µA sleep, 12 mA peak (2ms forced read)
- **Breakout:** Common BME280 modules from Adafruit, Pimoroni, or generic Aliexpress. Any I2C breakout works.
- **Notes:** Needs a radiation shield for accurate temp/RH. Without one, sun heats the sensor and readings are garbage. A simple louvered 3D-printed Stevenson screen works.

### 4. DS3231 (RTC)

- **Interface:** I2C (address 0x68 — no conflict with BME280)
- **Power:** 3.3V (VCC) + CR1220 coin cell (backup)
- **Accuracy:** ±2 ppm (temperature-compensated crystal oscillator)
- **Drift:** ±5 minutes over 6 months (uncorrected)
- **Current:** 0.8 µA (battery-backup mode)
- **Breakout:** Common DS3231 "Tiny RTC" or "Precision RTC" modules. Most include a CR1220 holder.
- **Notes:** Some cheap DS3231 modules ship with a rechargeable LIR2032 battery + charging circuit. **Remove the charging circuit** (cut trace or remove diode) if using a primary CR1220 — charging a non-rechargeable coin cell is a fire hazard.

#### GPS time sync (via SIM7080G GNSS)

The SIM7080G has a built-in GNSS receiver (GPS, GLONASS, Galileo, BeiDou). We use it to periodically sync the DS3231 RTC, eliminating long-term drift:

- **Without sync:** ±2 ppm → ±5 min drift over 6 months. Acceptable but not great for correlating wind events with weather data from other stations.
- **With daily GPS sync:** Drift reset to ±0 every day. Effective accuracy = drift per day ≈ ±0.17s/day (±2 ppm × 86400s). Negligible.
- **Sync schedule:** Once per day (piggyback on a modem wake cycle). GNSS cold fix takes 30–60s, warm fix <5s. Only the first sync is cold; subsequent daily syncs are warm since the modem keeps almanac in RTC memory.
- **Power cost:** GNSS active current ~60–100 mA for ~30–60s once per day. Averaged: 100mA × 45s / 86400s = **~0.052 mA** added to the daily average. Negligible — adds 0.14 Ah over 6 months.
- **Firmware flow:** Main core wakes modem (DTR LOW) → AT+CGNSPWR=1 (enable GNSS) → wait for fix (AT+CGNSINF, poll until valid) → parse UTC time → write to DS3231 via I2C → AT+CGNSPWR=0 (disable GNSS) → modem back to PSM.
- **Antenna:** GNSS uses a separate antenna from LTE. The SIM7080G breakout should have a GNSS antenna pad (usually labeled GNSS or GPS). A small passive patch antenna (25×25mm, ~$2) mounted with sky view is sufficient. Active antennas draw ~10–20 mA continuously — avoid for battery operation; we only enable GNSS for 60s/day.
- **Fallback:** If GPS fix fails (heavy overcast, snow cover on antenna, indoor test), DS3231 continues on its own. Next day's sync attempt catches up. No data loss — timestamps just drift slightly until next successful fix.
- **CR1220 backup:** Still needed. The DS3231's coin cell keeps time during the gap between manufacturing/programming and first deployment, and during any extended GNSS outage. The coin cell is the always-on clock; GPS is the correction.

### 5. Piezo Rain Sensor — DIY Disdrometer

- **Interface:** Analog voltage (ADC, GPIO0)
- **Power:** 3.3V (passive — piezo generates its own voltage, no power needed except op-amp if used)
- **Type:** Piezoelectric disc impact disdrometer (no moving parts)
- **Cost:** ~$2-5

#### How it works

A piezo disc is bonded to the underside of a flat rigid plate (acrylic, polycarbonate, or thin PCB). Raindrops hit the plate, transferring kinetic energy through the plate to the piezo, which generates a voltage spike proportional to the impact force. Bigger drops = bigger spikes. More drops per second = higher rain rate.

The piezo signal is bipolar AC (mV to several volts). A simple conditioning circuit biases it to VCC/2, clamps the peaks to protect the ADC, and optionally a peak detector holds the maximum between samples.

#### Signal conditioning circuit (v1 — passive peak-hold with voltage doubler)

```
              D1 (1N4148)
  Piezo ──┬──→|──┬──────────┐
   (+/-)  │      │          │
          │   C1  │  D2     │
          │   1nF │ (1N4148)│
          │      │  ┌──→|──┬─┴── 10kΩ ── GPIO0 (ADC)
          │      └──┘      │
          │               C2
          │            470nF film
          │               │
          │          ┌────┴────┐
          │          │ 2N7002  │  gate → GPIO8 (reset)
          │          └────┬────┘  10kΩ pulldown on gate
          │               │
  Piezo ──┴───────────────┴── GND
```

**How it works:**

- D1 + C1 form a charge pump (Greinacher voltage doubler) — captures both AC half-cycles from the piezo and doubles the peak voltage onto C2
- D2 is the peak-hold diode — C2 charges to the highest impact voltage seen since last reset
- C2 (470nF film) holds the peak — film dielectric for negligible self-leakage (hours)
- 2N7002 N-MOSFET on GPIO8 discharges C2 after each ADC read — 5ms pulse to reset, clean window for next interval
- 10kΩ on ADC input is series protection, not a bleed — the only discharge paths are 1N4148 reverse leakage (~5nA) and ADC sampling
- 10kΩ pulldown on MOSFET gate ensures it stays OFF during deep sleep (gate = 0V)

**Why no Schottky diodes:** 1N4148 has higher forward drop (0.7V vs 0.3V) but much lower reverse leakage (~5nA vs ~2µA). The piezo produces 5-20V open-circuit, so 0.7V forward drop is irrelevant. Lower leakage is critical — it's what lets us use a small hold cap (470nF) and still retain the peak across 60s.

**Why no bleed resistor:** With MOSFET reset, the bleed resistor is an intentional leakage path that wastes signal. Removed. The MOSFET is the controlled discharge path.

**Why voltage doubler:** The piezo output is AC. A single diode throws away half the energy. The doubler captures both half-cycles for ~2× signal — free improvement, one extra diode + cap.

**Signal levels (estimated):**

| Drop size | Charge (approx) | Voltage on C2 (doubled) | After 60s hold (5nA leak) |
|---|---|---|---|
| Light drizzle | ~50nC | ~210mV | ~146mV ✅ |
| Moderate | ~150nC | ~640mV | ~576mV ✅ |
| Heavy | ~300nC | ~1.28V | ~1.21V ✅ |

ESP32-C6 ADC: 12-bit, 0-3.3V → 0.8mV resolution. Light drizzle (~146mV after hold) = ~182 ADC counts — well above noise floor.

**BOM:**

| Ref | Part | Value | Cost |
|-----|---|---|---|
| D1, D2 | 1N4148 | signal diode | ~$0.02 |
| C1 | 1nF ceramic | charge pump | ~$0.01 |
| C2 | 470nF film | hold cap (low leakage) | ~$0.10 |
| Q1 | 2N7002 | N-MOSFET reset | ~$0.03 |
| R1 | 10kΩ | ADC series protection | ~$0.01 |
| R2 | 10kΩ | MOSFET gate pulldown | ~$0.01 |
| **Total** | | | **~$0.20** |

**Firmware:** Main core reads ADC as burst (16 reads, take max), then pulses GPIO8 HIGH for 5ms to discharge C2. Read happens on 1-minute wake cycle. The peak-hold circuit captures the highest raindrop impact across the full 60s window.

#### Signal conditioning circuit (v2 — with op-amp, if v1 lacks sensitivity)

```
Piezo disc ──┬── 1N4148 clamps (to GND and 3.3V)
            └── OPA376 (gain = 10×, 0.9 µA quiescent)
                 └── Peak detector (1N4148 + 10nF cap + 10MΩ bleed)
                      └── ADC input (GPIO0)
```

OPA376: 0.9 µA quiescent, rail-to-rail, $1.50. Gain of 10× brings mV-level drizzle signals into the ADC's usable range. Peak detector holds the max impact voltage between 5s samples.

#### Catch surface design

- **Material:** 3mm acrylic (PMMA), 60mm diameter — precut discs widely available, cheaper than polycarbonate, UV-stable. Stiffer than polycarbonate (sharper impact peaks) but won't shatter like glass. Some ringing after impact but less than glass — acceptable for v1.
- **Piezo:** 35mm passive piezo disc element (brass + ceramic, no driver circuit, ~$0.50)
- **Mounting:** Piezo bonded to center of plate underside with epoxy. 12.5mm rim around piezo for bonding + mounting. Disc mounted level, exposed to sky.
- **Drainage:** Slight tilt or textured surface so water doesn't pool. Pooling dampens the signal.
- **Catch area:** 28 cm² (60mm diameter) — slightly above the 20 cm² literature sweet spot. Large enough to catch drops, small enough that simultaneous impacts rarely overlap even in heavy rain.
- **Piezo size rationale:** 35mm chosen over 27mm for higher sensitivity (~2× capacitance → higher voltage per impact). Important for v1 with no op-amp — need maximum raw signal for light rain detection. 27mm is the fallback if 35mm is unavailable.
- **Plate size rationale:** 60mm chosen over 50mm to give adequate rim space (12.5mm) for epoxy bonding around a 35mm piezo. 50mm would leave only 7.5mm rim — tight for reliable bonding.
- **Material rationale:** Acrylic chosen over polycarbonate (cheaper precuts, UV-stable, stiffer = sharper peaks) and glass (shatters in hail). Aluminum disc (0.5mm) is the acoustic upgrade path if signal quality needs improvement.

#### Calibration

Piezo output is not in mm/hr — it's a raw voltage/impact count. Calibration maps the signal to rain rate. Several approaches from the literature:

1. **Simple threshold counting:** Count ADC peaks above a threshold per interval. More peaks = more rain. Crude but functional. Calibrate against a reference gauge by finding the threshold and scaling factor that matches.

2. **Peak amplitude integration:** Sum (or average) the peak amplitudes per interval. Higher amplitude = bigger drops = more rain. Better correlation with rain rate than pure count.

3. **ML-based calibration:** Train a model (random forest, etc.) on features extracted from the signal (peak count, peak amplitude distribution, RMS energy, frequency content) against a reference rain gauge. Best accuracy per the research literature.

4. **Field calibration:** Deploy alongside a known reference (tipping bucket, manual gauge, or nearby weather station) for a few rain events. Correlate raw piezo data with known rain rates. Derive a calibration curve. Apply retroactively to the full dataset.

For v1: **log raw ADC peak values** (peak amplitude per 5s interval). Calibrate later against a reference. The raw data is preserved — any calibration method can be applied retroactively.

#### Reference designs and literature

| Source | What it provides | Link |
|---|---|---|
| **Delft University disdrometer** | Full DIY build guide with circuit, firmware, and calibration approach. Instructables with photos and code. | [instructables.com](https://www.instructables.com/Make-an-acoustic-rain-gauge-disdrometer/) |
| **IOPScience — piezo-buzzer disdrometer** | Academic paper with full circuit (sensor → op-amp → filter → ADC), Arduino firmware, and calibration against a reference gauge. Uses DS3231 RTC (same as us!). | [iopscience.iop.org](https://iopscience.iop.org/article/10.1088/1742-6596/2034/1/012023/pdf) |
| **MDPI — ML calibration paper** | Low-cost piezo sensor with ML-based calibration. Extracts signal features and trains models against reference rain gauge data. Best accuracy approach. | [mdpi.com](https://www.mdpi.com/1424-8220/22/17/6638) |
| **Ravi Bagree thesis** | Detailed readout circuit characterization for piezo disdrometer. Covers impedance matching, gain stages, and noise analysis. | [scribd.com](https://www.scribd.com/document/273071512/) |
| **ICFOSS Acoustic Raingauge** | Open source GitHub project. Uses acoustic sensors + ML to estimate precipitation. Python analysis scripts included. | [github.com/harikrishnan-kp/Acoustic_Raingauge](https://github.com/harikrishnan-kp/Acoustic_Raingauge) |
| **Analog Devices CN-0350** | Charge-mode piezo sensor ADC reference design. Industrial-grade signal chain for piezoelectric sensors. Overkill but good theory. | [analog.com](https://www.analog.com/media/en/reference-design-documentation/reference-designs/CN0350.pdf) |
| **"Affordable Acoustic Disdrometer" paper** | Design, calibration, and field tests of a low-cost piezo disdrometer. 20 cm² catch area, validates the approach. | [researchgate.net](https://www.researchgate.net/publication/241375116_Affordable_Acoustic_Disdrometer_Design_Calibration_Tests) |

#### Power

| Component | Current | Notes |
|---|---|---|
| Piezo disc (passive) | 0 µA | Generates its own voltage, no power needed |
| Peak-hold circuit (passive) | ~0 µA | 1N4148 leakage ~5nA, film cap self-discharge negligible. No DC path to VCC. |
| 2N7002 gate pulldown | 0 µA | Gate held LOW in sleep, no current flow |
| Op-amp (OPA376, if used in v2) | 0.9 µA | Only needed for v2 with amplification |
| **Total (v1, peak-hold)** | **~0 µA** | Negligible — no bias divider needed |
| **Total (v2, with op-amp)** | **~1.1 µA** | Still negligible |

### 6. SIM7080G (LTE-M modem uplink)

- **Module:** SIMCom SIM7080G (Cat-M1 + NB-IoT, LGA)
- **Breakout:** Ordered by goos — 8-pin breakout with VBAT, GND, VCC, GND, RXD, TXD, DTR, PWR
- **LTE class:** Cat-M1 (eMTC) — AT&T's committed IoT technology
- **Max downlink/uplink:** 0.3 / 0.37 Mbps (Cat-M1)
- **Sleep current (PSM):** ~3 µA (module only), ~10–50 µA realistic board-level
- **Active current:** ~200–600 mA TX bursts (Cat-M1)
- **Bands (global G variant):** B1, B2, B3, B4, B5, B8, B12, B13, B18, B19, B20, B25, B26, B27, B28, B66, B71, B85
- **AT&T bands:** B2, B4, B5, B12, B17 (via B12), B66, B71
- **GNSS:** GPS, GLONASS, Galileo, BeiDou — used for daily RTC sync (see below)
- **Host interface:** UART (115200 baud, AT commands)
- **SIM voltage:** 1.8 V only — need 1.8 V-compatible IoT SIM
- **Power supply:** VBAT pin takes raw battery voltage (3.6V Li-SOCl2), VCC pin takes 3.3V logic reference from LDO
- **Antenna:** External directional Yagi (700 MHz primary), SMA connector on breakout
- **PSM (Power Saving Mode):** Modem stays registered to network while sleeping at ~3 µA. Wake via DTR LOW, upload data, sleep via DTR HIGH. Reconnection takes seconds, not 30–60s cold attach.
- **See:** [lte-uplink.md](lte-uplink.md) for full modem analysis, antenna selection, SIM plan, and power budget

#### Pin mapping (modem breakout → ESP32-C6)

| Modem pin | ESP32-C6 pin | Function | Notes |
|---|---|---|---|
| VBAT | Raw battery (before LDO) | Modem main power | 3.6V from Li-SOCl2. LC filter (L1 1µH + 3× 100µF ceramic) for Cat-M1 TX spikes. |
| GND | GND | Ground | 2× GND pins on breakout, tie both to common ground |
| VCC | 3.3V LDO output | Logic level reference | 3.3V from HT7333 rail. Powers level shifters / reference on breakout. |
| RXD | GPIO16 (UART0 TX) | ESP32 → modem | 115200 baud, AT commands |
| TXD | GPIO17 (UART0 RX) | Modem → ESP32 | 115200 baud, AT responses |
| DTR | GPIO15 | PSM sleep/wake | HIGH = modem sleeps (PSM), LOW = modem awake. 10kΩ pull-up = sleeps during boot. |
| PWR | GPIO9 | Power key | Pulse LOW ≥1s to toggle power on/off. 10kΩ pull-up (boot-safe). |

#### Power supply notes

The SIM7080G's VBAT pin draws directly from the Li-SOCl2 battery (before the LDO) because:
1. **Cat-M1 TX spikes hit 600 mA** — the HT7333 LDO is rated for 250 mA max
2. **Li-SOCl2 D-cells can deliver ~100 mA continuous** but Cat-M1 TX is duty-cycled (short bursts)
3. An **LC filter** (L1 1µH inductor + 3× 100µF ceramic caps) on VBAT handles the TX current spikes; the battery provides the average current
4. The LDO output (3.3V, 250 mA) powers VCC (logic reference) which draws only mA-level current

**VBAT power filtering — LC filter + bulk capacitance**

Li-SOCl2 batteries have high internal resistance (~10–50Ω per cell, 5–25Ω with 2 cells in parallel). Cat-M1 TX bursts hit ~600 mA for ~0.5ms, repeating every ~20ms during active transmission. Without filtering, VBAT sags below the modem's 3.4V minimum and the modem resets.

SIMCom's hardware design guide recommends an LC filter on VBAT — this is the standard approach for all SIMCom LTE modems:

```
  Battery + ──[ L1 ] ──┬── VBAT (modem)
                      │
              ┌───────┼───────┬───────┐
              │       │       │       │
           C1 100µF  C2 100µF C3 100µF C4 10µF
            (ceramic) (ceramic) (ceramic) (ceramic)
              │       │       │       │
              └───────┼───────┴───────┘
                      │
                   C5 100nF  C6 33pF
                   (ceramic) (ceramic)
                      │
  Battery − ──────────┴── GND
```

**Why an inductor (L1) instead of just a resistor:**
- A resistor would limit current but waste power continuously (I²R loss at the modem's ~50 mA active current)
- An inductor has near-zero DC resistance (DCR < 0.1Ω) — negligible steady-state loss
- During TX spikes, the inductor's impedance (ZL = 2πfL) blocks high-frequency current from reaching back to the battery — the cap bank supplies the burst instead
- Between bursts, the inductor lets the cap recharge from the battery at a sustainable rate (~50–100 mA, well within Li-SOCl2 capability)

**Why three 100µF caps instead of one 330µF:**
- ESR (equivalent series resistance): three 100µF ceramics in parallel ≈ 1.7mΩ total. One 330µF electrolytic ≈ 100–300mΩ. Low ESR is what delivers the multi-amp spike current without voltage droop.
- ESL (equivalent series inductance): parallel ceramics have lower ESL than a single large cap — better high-frequency response.
- Ceramic caps also have vastly better cold-temperature performance than electrolytics (ESR stays low at -40°C, electrolytic ESR can 10× at cold).

**Component values:**

| Ref | Part | Value | Notes |
|---|---|---|---|
| L1 | Power inductor or ferrite bead | 1–2.2 µH, DCR < 0.1Ω, saturation current ≥ 2A | SMD (e.g. 0805/1206). Low DCR critical — higher DCR wastes power. Saturation current must exceed worst-case TX spike. |
| C1–C3 | Ceramic cap, X5R/X7R | 3× 100µF, 6.3V+, 0805/1206 | X7R for cold temp stability. Parallel for low ESR/ESL. Place as close to VBAT pins as possible. |
| C4 | Ceramic cap, X7R | 10µF, 6.3V, 0603 | Mid-frequency bypass |
| C5 | Ceramic cap, X7R | 100nF, 0402 | High-frequency bypass |
| C6 | Ceramic cap, C0G/NP0 | 33pF, 0402 | RF noise bypass (near VBAT pins) |
| TVS | TVS diode (optional) | ~5V standoff, SMA/SMB | ESD protection on VBAT per SIMCom recommendation |

**Energy budget check:**

- Energy stored in 300µF cap bank at 3.6V: E = ½CV² = ½ × 0.0003 × 3.6² = **1.94 mJ**
- Energy per Cat-M1 TX burst (600 mA × 3.6V × 0.5ms): E = V×I×t = 3.6 × 0.6 × 0.0005 = **1.08 mJ**
- Cap bank has 1.8× the energy for a single burst. With the inductor limiting recharge rate, the cap bank handles 1–2 bursts before needing recharge. Cat-M1 typically bursts every 20ms during a ~30s active period — the cap recharges between bursts via the inductor at ~50 mA (battery's safe continuous rate), which is enough to sustain the duty cycle.

**Alternative: pre-built LC filter module**

Pre-built power filter modules (e.g. "LC power filter module" from Amazon/AliExpress, ~$2–5) bundle an inductor + caps in a tiny PCB. These work but check:
- Inductor saturation current (must be ≥ 2A for Cat-M1)
- Cap values and type (must be ceramic, not electrolytic, for low ESR at cold)
- DCR of the inductor (must be < 0.1Ω to avoid wasting power in sleep)

A DIY SMD build on a small breakout is better — you control the component quality and can tune values. But a pre-built module is fine for prototyping.

**What the breakout board may already include:**

The SIM7080G breakout goos ordered may already have some VBAT decoupling on the PCB. Check the breakout board's BOM before duplicating. If it has 100µF+ on VBAT, add only the inductor (L1) in series between the battery and the breakout's VBAT input. If it has minimal decoupling, add the full LC filter externally.

**Updated power tree with LC filter:**

```
VBAT (3.6V, 38Ah)
  ├─ [L1 1µH] ── [C1-C6 bulk/bypass] ── SIM7080G VBAT
  └─ HT7333 LDO (3.3V, ~1µA Iq)
       ├─ ESP32-C6 SuperMini (3V3 pin)
       ├─ WindNerd Core (VCC)
       ├─ BME280 (VCC)
       ├─ DS3231 (VCC)
       ├─ SD card (VCC)
       ├─ SIM7080G VCC (logic level reference, 3.3V)
       ├─ Q2 AO3401 source → OLED VCC (when gated on)
       └─ Piezo circuit (GND reference only — no DC power)
```

### 7. MCP23008 (I2C GPIO Expander)

- **Chip:** MCP23008 — 8-bit I2C expander with interrupt output
- **I2C address:** 0x20 (A0=A1=A2=GND) — no conflict with BME280 (0x76), DS3231 (0x68), OLED (0x3C)
- **Voltage:** 3.3V (VCC from LDO rail)
- **Standby current:** ~1 µA
- **Internal pull-ups:** 100kΩ per pin — no external resistor bank needed for buttons
- **Interrupt:** Active-low INT output → ESP32-C6 GPIO14. Wakes ESP32 on any pin change.
- **Breakout:** Common MCP23008 breakout boards from Adafruit, SparkFun, or generic AliExpress. 8-pin SIP, 2.54mm pitch.

#### Pin mapping (MCP23008 → OLED/encoder board)

| MCP23008 pin | Function | Notes |
|---|---|---|
| GP0 | ENC_A (encoder clock) | Input, pull-up via expander |
| GP1 | ENC_B (encoder data) | Input, pull-up via expander |
| GP2 | ENC_PSH (encoder push) | Input, pull-up via expander |
| GP3 | CON_BTN (confirm) | Input, pull-up via expander. INT wakes ESP32 on falling edge. |
| GP4 | BAK_BTN (back/sleep) | Input, pull-up via expander |
| GP5 | spare | Available for future expansion |
| GP6 | spare | Available for future expansion |
| GP7 | spare | Available for future expansion |
| INT | → ESP32-C6 GPIO14 | Active-low interrupt output |
| SDA | ESP32-C6 GPIO6 | Shared I2C bus |
| SCL | ESP32-C6 GPIO7 | Shared I2C bus |
| VCC | 3.3V LDO | |
| GND | GND | |

#### Why MCP23008 over PCF8574

- **Per-pin direction control:** PCF8574 is quasi-bidirectional only — can't mix inputs and outputs cleanly
- **Internal pull-ups:** MCP23008 has 100kΩ pull-ups per pin — saves 5× external resistors for buttons
- **Proper interrupt output:** MCP23008 has a dedicated INT pin with configurable polarity (active-low by default). PCF8574's interrupt is less flexible.
- **Lower standby:** MCP23008 ~1 µA vs PCF8574 ~3-5 µA

#### Encoder over I2C latency

Manual encoder rotation produces ~10-20 detents/sec, each transition 50-100ms apart. I2C reads the port register in ~100µs. The INT fires on any pin change, ESP32 wakes (~3ms), reads state over I2C, processes, returns to sleep. Total latency ~5ms per event — imperceptible to a human. Only used during interactive mode anyway (OLED on, user physically present).

### 8. MicroSD Card Module

#### Does the chipset matter?

**No.** SD card modules are dumb SPI-to-SD-card adapters. The "chipset" is just a level shifter (or not) and an SD card slot. The ESP32-C6 handles all SD protocol in firmware via SPI.

What matters:

| Factor | Why it matters |
|---|---|
| **Voltage** | Must be 3.3V logic. Some cheap modules have a 5V→3.3V LDO + level shifter (the "CATALEX" style). These work but waste power in the LDO. A bare 3.3V SPI microSD breakout is better for low power. |
| **SPI vs SDIO** | SPI mode uses 4 pins (MOSI, MISO, SCK, CS). SDIO mode uses 6 pins but is faster. We don't need speed — SPI is fine and saves 2 pins. |
| **Slot quality** | Cheap modules have flaky card slots. A proper spring-loaded microSD holder matters for 6 months of vibration/wind. |
| **No onboard LED** | Some modules have a power LED. Desolder it — wastes ~1 mA constantly. |

#### Recommended module

**Bare SPI microSD breakout (3.3V, no level shifter, no LED).**

Common options:
- **Adafruit microSD SPI breakout** — $4.95, clean 3.3V design, no LED, reliable slot
- **SparkFun microSD Transflash breakout** — similar
- **Generic "microSD SPI module" (no LDO version)** — $1-2 on Aliexpress. Look for ones without the AMS1117 LDO chip. If it has an LDO, it's the 5V-compatible version — works but wastes power.

**Key:** Get one that's 3.3V-only (no LDO, no level shifter). The ESP32-C6 is 3.3V logic — direct SPI is cleanest and lowest power.

#### Wiring

| SD pin | ESP32-C6 GPIO | Notes |
|---|---|---|
| VCC (3.3V) | 3.3V | Direct from ESP32-C6 3.3V rail |
| GND | GND | |
| MOSI | GPIO assigned | SPI MOSI |
| MISO | GPIO assigned | SPI MISO |
| SCK | GPIO assigned | SPI clock |
| CS | GPIO assigned | Chip select (active low) |

#### SD card

- **Capacity:** 8 GB (we need ~168 MB for 6 months — 8 GB has 47× headroom)
- **Type:** Industrial pSLC for cold + power-loss resilience
- **Recommended:** Transcend Industrial 8GB (-40°C) or SanDisk High Endurance 32GB
- **Format:** FAT32 (8 GB or smaller) or exFAT (larger). FAT32 is simpler and well-supported on ESP32.

---

## Pin Allocation — ESP32-C6 SuperMini

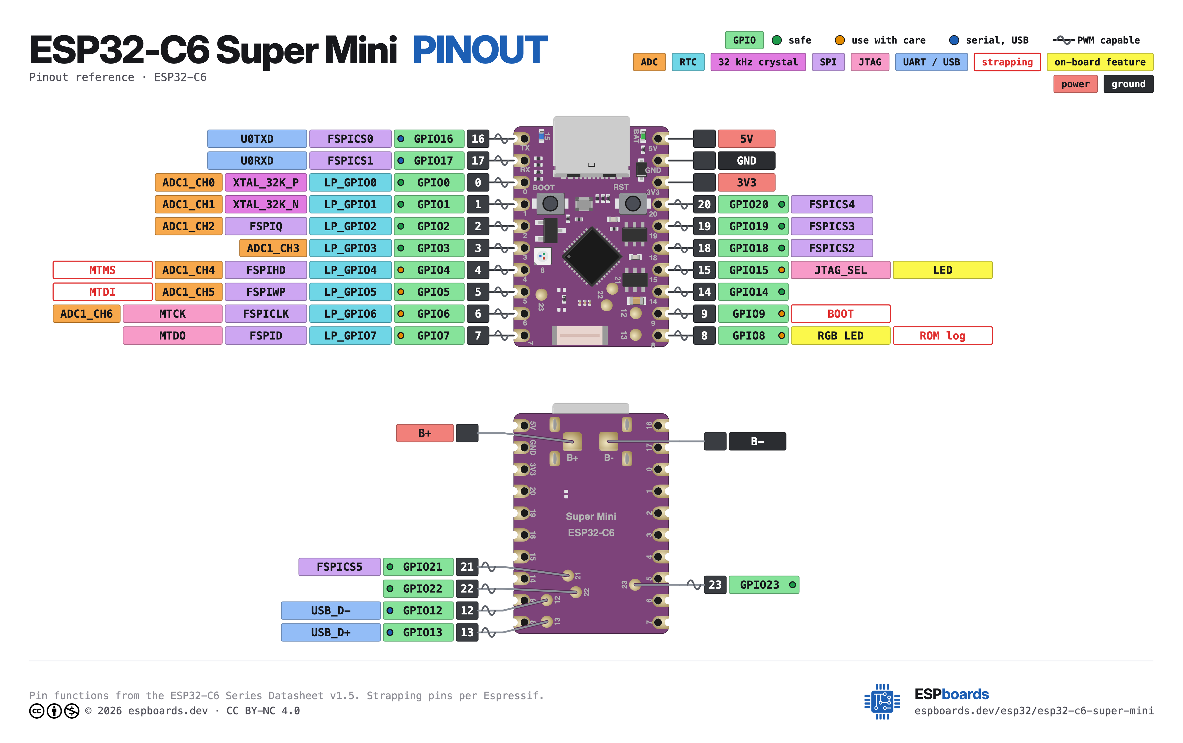
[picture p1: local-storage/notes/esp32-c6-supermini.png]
espboards.dev esp32-c6-supermini

> esp32-c6 supermini from <https://www.espboards.dev/esp32/esp32-c6-super-mini/#pinout>

The ESP32-C6 SuperMini breaks out **22 GPIO** with silkscreen labels 0–9, 12–15, 16(TX), 17(RX), 18–23. GPIO10 and GPIO11 are **not broken out** — internal flash pins.

**Board layout** (USB port facing up):

| Left side | → | Right side |
|---|---|---|
| 16, 17, 0, 1, 2, 3, 4, 5, 6, 7, 23, 22 | | 5V, GND, 3V3, 20, 19, 18, 15, 14, 9, 8, 12, 13, 21 |

**Safe pins** (no boot/system duties): 0, 1, 2, 3, 14, 18, 19, 20, 21, 22, 23
**Strapping pins**: 2, 4, 5, 6, 7, 8, 9, 15
**UART0**: 16 (TX), 17 (RX) — free if using native USB for programming
**USB**: 12 (D−), 13 (D+) — do not use
**Onboard LEDs**: 8 (WS2812 RGB), 15 (status LED) — keep off in firmware for low power

| Silkscreen | GPIO | Function | Core | Pin status | Capabilities | Notes |
|---|---|---|---|---|---|---|
| 0 | GPIO0 | **ADC — piezo rain** | LP core | safe | ADC1_CH0, LP_GPIO0 | LP core reads ADC at 5s. Low-noise analog pin. |
| 1 | GPIO1 | **WindNerd trigger (output)** | LP core | safe | ADC1_CH1, LP_GPIO1 | LP core toggles every 5s to wake WindNerd |
| 2 | GPIO2 | **SPI SCK (SD card)** | Main core | strapping | ADC1_CH2, LP_GPIO2, FSPIQ | SD card clock. SPI clock idles low — 10kΩ pull-down keeps boot-safe. |
| 3 | GPIO3 | **SPI CS (SD card)** | Main core | safe | ADC1_CH3, LP_GPIO3 | SD card chip select (active low). 10kΩ pull-up keeps CS high during boot. |
| 4 | GPIO4 | **UART RX from WindNerd** | LP core | strapping | ADC1_CH4, LP_GPIO4, LP_UART_RXD, MTMS | LP_UART RX. UART idles high — 10kΩ pull-up keeps boot-safe. |
| 5 | GPIO5 | **OLED VCC MOSFET gate** | Main core | strapping | ADC1_CH5, LP_GPIO5, LP_UART_TXD, MTDI | P-channel MOSFET gate. 10kΩ pull-up = OFF during boot. LOW = OLED on. |
| 6 | GPIO6 | **I2C SDA (BME280 + DS3231 + OLED)** | Main core | strapping | ADC1_CH6, LP_GPIO6, MTCK, FSPICLK | Shared I2C bus, three devices (0x76, 0x68, 0x3C) |
| 7 | GPIO7 | **I2C SCL (BME280 + DS3231 + OLED)** | Main core | strapping | LP_GPIO7, MTDO, FSPID | Shared I2C bus |
| 8 | GPIO8 | **Rain peak-hold reset (2N7002 gate)** | Main core | strapping | WS2812 RGB LED | Pulses HIGH 5ms to discharge 470nF hold cap after ADC read. 10kΩ pulldown = OFF during sleep. Onboard RGB LED stays OFF. |
| 9 | GPIO9 | **SIM7080G PWR (power key)** | Main core | strapping | BOOT button | Pulse LOW ≥1s to power modem on/off. 10kΩ pull-up (boot-safe). |
| 12 | GPIO12 | — RESERVED | — | USB | USB_D− | Native USB (programming). Do not use. |
| 13 | GPIO13 | — RESERVED | — | USB | USB_D+ | Native USB (programming). Do not use. |
| 14 | GPIO14 | **MCP23008 INT (I2C expander interrupt)** | Main core | safe | General purpose | Interrupt from MCP23008 — wakes ESP32 on encoder/button pin change |
| 15 | GPIO15 | **SIM7080G DTR (PSM control)** | Main core | strapping | JTAG, LED | HIGH = modem sleeps (PSM), LOW = modem awake. 10kΩ pull-up = modem sleeps during boot. |
| 16 (TX) | GPIO16 | **SIM7080G RXD (UART0 TX)** | Main core | uart | UART0 TX, FSPICS0 | ESP32 TX → modem RX. 115200 baud. Native USB used for programming, UART0 free for modem. |
| 17 (RX) | GPIO17 | **SIM7080G TXD (UART0 RX)** | Main core | uart | UART0 RX, FSPICS1 | Modem TX → ESP32 RX. 115200 baud. |
| 18 | GPIO18 | **SPI MOSI (SD card)** | Main core | safe | SDIO CMD, FSPICS2 | SD card data out |
| 19 | GPIO19 | **SPI MISO (SD card)** | Main core | safe | SDIO CLK, FSPICS3, I2C SCL (alt) | SD card data in |
| 20 | GPIO20 | **FREE** | — | safe | SDIO DATA0, FSPICS4, I2C SDA (alt) | Spare — freed by moving encoder to MCP23008 |
| 22 | GPIO22 | **FREE** | — | safe | SDIO DATA2 | Spare — freed by moving CON button to MCP23008 |
| 23 | GPIO23 | **FREE** | — | safe | SDIO DATA3 | Spare — freed by moving BAK button to MCP23008 |

**Summary:**

| Category | Count | Silkscreen pins |
|---|---|---|
| Used (LP core) | 3 | 0 (ADC), 1 (trigger), 4 (UART RX) |
| Used (main core) | 13 | 2 (SCK), 3 (CS), 5 (MOSFET), 6 (SDA), 7 (SCL), 8 (rain reset), 9 (modem PWR), 14 (expander INT), 15 (modem DTR), 16 (modem TX), 17 (modem RX), 18 (MOSI), 19 (MISO) |
| Reserved (USB) | 2 | 12, 13 |
| **Free** | **3** | 20, 22, 23 |

**3 free GPIO** (IO20, IO22, IO23). Encoder + buttons moved to MCP23008 I2C expander (address 0x20) on shared I2C bus. MCP23008 INT → GPIO14 wakes ESP32 on any pin change. GPIO10/GPIO11 don't exist on this board. GPIO21 does not exist as a pad on the SuperMini board.

### Pin assignment rationale

- **LP core pins (0–4):** The LP RISC-V core can only access LP_GPIO0–7. We use pin 0 for ADC (piezo), pin 1 for trigger output, and pin 4 for LP_UART RX. All three are LP-accessible.
- **LP_UART on pin 4:** The ESP32-C6's LP_UART defaults to GPIO4 (RXD) and GPIO5 (TXD). We only need RX (WindNerd sends data, we don't send back). Pin 4 is a strapping pin (MTMS) but UART idles high, so a 10kΩ pull-up keeps it boot-safe.
- **I2C on pins 6/7:** Shared I2C bus with three devices: BME280 (0x76), DS3231 (0x68), SH1106 OLED (0x3C). No address conflicts. These are the LP_I2C default pins but we use them with the main core's I2C peripheral.
- **SPI on pins 2/3/18/19:** SPI is remapped via GPIO matrix. Pins 2/3 are on the left header, pins 18/19 on the right header. All avoid USB and are safe/low-conflict. Pins 10/11 do not exist on this board. We deliberately choose SPI mode (4 pins) over SDIO mode (6 pins) because the data rate is trivial (~838 KB/day, 70-byte appends once per minute). SDIO's speed advantage is irrelevant when the SD card is asleep 55s out of every 60s.
- **ADC on pin 0:** ADC1_CH0, lowest-conflict ADC pin. LP core reads it at 5s intervals.
- **OLED on shared I2C:** SH1106 1.3" OLED shares the pin 6/7 I2C bus. Address 0x3C — no conflict. Display is power-gated by P-channel MOSFET (AO3401), gate on GPIO5 (firmware-controlled, not tied to a switch). 10kΩ pull-up on gate keeps MOSFET off during boot/deep sleep. Zero current when off.
- **Rotary encoder + buttons on MCP23008 I2C expander:** EC11 encoder (TRA/TRB/PSH) and CON/BAK buttons all connect to an MCP23008 8-bit I2C expander at address 0x20. The expander's INT output connects to GPIO14 on the ESP32-C6, which wakes the main core on any pin change. This frees GPIO20, GPIO22, and GPIO23 for future use, and solves the GPIO21 problem (that pad doesn't exist on the SuperMini board). MCP23008 has internal pull-ups, so no external resistor bank needed for the buttons. Standby current ~1 µA — negligible in the power budget.
- **CON button on MCP23008 GP3:** Momentary button to GND with internal pull-up. CONFIRM button in interactive UI. INT wakes ESP32 on falling edge.
- **BAK button on MCP23008 GP4:** Momentary button to GND with internal pull-up. BACK button in interactive UI. At top-level menu, pressing BAK returns the station to low-power mode (power off OLED, stop WiFi, enter deep sleep).
- **OLED MOSFET gate on pin 5:** GPIO5 drives the P-channel MOSFET gate for OLED power gating. HIGH = OLED off (pull-up ensures off during boot), LOW = OLED on. GPIO5 is strapping (MTDI) but 10kΩ pull-up = HIGH during boot = normal boot mode. Safe.
- **Exit interactive mode:** 60s inactivity timeout (auto-sleep), or explicit "Sleep" menu option (navigate with encoder, confirm with CON), or press BAK at top-level menu. A separate "Halt" option (full system stop, requires power cycle) may be added in a future revision.
- **Onboard LEDs:** Pin 8 (WS2812 RGB) and pin 15 (status LED) have onboard LEDs. Both are strapping pins and left free. Firmware must keep them OFF — the WS2812 draws ~1 mA even when showing black. Desolder the RGB LED if it causes sleep current issues.

### Deep sleep current note

Per [measurements on this exact board](https://dmelo.eu/blog/esp32c6_deepsleep/), deep sleep current is in the **tens of microamps** — higher than the ESP32-C6 datasheet's bare-module figure of ~7 µA. The onboard LTH7R charger IC and passive components add overhead. Our power budget estimate (~0.018 mA for ESP32-C6) may be optimistic by 2-5×. **Plan to measure actual sleep current on the specific board** and update the power budget accordingly. Desoldering the RGB LED (pin 8) and status LED (pin 15) may help reduce sleep current.

---

## Inter-board Wiring

### WindNerd Core ↔ ESP32-C6

| WindNerd pin | ESP32-C6 pin | Wire color | Function |
|---|---|---|---|
| TX2 (yellow) | GPIO4 (LP_UART RX) | Yellow | Wind data output → ESP32-C6 LP core reads |
| GND | GND | Black | Common ground |
| GPIO (trigger) | GPIO1 | Green | ESP32-C6 LP core triggers WindNerd read |
| VCC | 3.3V (LDO) | Red | WindNerd powered from shared 3.3V LDO rail |

**Notes:**
- UART is one-way (WindNerd TX → ESP32-C6 RX). No need for RX on WindNerd — the trigger is a separate GPIO, not UART.
- Pull-up resistor (10kΩ) on the trigger line — keeps WindNerd's GPIO stable during ESP32 deep sleep.
- UART line: 9600 baud, short distance (inside enclosure, ~10cm). No level shifter needed — both are 3.3V logic.

### BME280 ↔ ESP32-C6

| BME280 pin | ESP32-C6 pin | Notes |
|---|---|---|
| VCC (3.3V) | 3.3V (LDO) | |
| GND | GND | |
| SDA | GPIO6 (I2C SDA) | Shared with DS3231 |
| SCL | GPIO7 (I2C SCL) | Shared with DS3231 |

### DS3231 ↔ ESP32-C6

| DS3231 pin | ESP32-C6 pin | Notes |
|---|---|---|
| VCC (3.3V) | 3.3V (LDO) | |
| GND | GND | |
| SDA | GPIO6 (I2C SDA) | Shared with BME280 + OLED |
| SCL | GPIO7 (I2C SCL) | Shared with BME280 + OLED |
| CR1220+ | — | Backup battery on DS3231 module |

### OLED + Rotary Encoder + Buttons Board ↔ ESP32-C6

The OLED+encoder board combines a 1.3" SH1106 OLED, EC11 rotary encoder, and two pushbuttons (CONFIRM and BACK) on a single breakout. Board pinout:

```
CON  SDA  SCL  PSH  TRA  TRB  BAK  GND  VCC
```

| Board pin | Connects to | Notes |
|---|---|---|
| CON | MCP23008 GP3 | CONFIRM button — internal pull-up, INT wakes ESP32 |
| SDA | ESP32-C6 GPIO6 (I2C SDA) | Shared bus (BME280 0x76 + DS3231 0x68 + OLED 0x3C + MCP23008 0x20) |
| SCL | ESP32-C6 GPIO7 (I2C SCL) | Shared bus |
| PSH | MCP23008 GP2 | Encoder push — internal pull-up |
| TRA | MCP23008 GP0 | Encoder A (clock) |
| TRB | MCP23008 GP1 | Encoder B (data) |
| BAK | MCP23008 GP4 | BACK button — internal pull-up. At top-level menu = enter low-power mode |
| GND | GND | Ground |
| VCC | 3.3V via MOSFET | Gated by P-channel MOSFET, gate on GPIO5 |

**MCP23008 INT → ESP32-C6 GPIO14:** The expander's active-low interrupt output connects to GPIO14. Any pin change (encoder rotation, button press) triggers INT, which wakes the ESP32-C6 from deep sleep. The ESP32 then reads the MCP23008 port register over I2C to determine which pin changed. |

**OLED power gating:** OLED VCC is switched via a P-channel MOSFET (AO3401). Gate is controlled by GPIO5 (firmware-driven, not tied to a switch). 10kΩ pull-up on gate to 3.3V keeps MOSFET off during boot/deep sleep. Firmware sets GPIO5 LOW to power on OLED, HIGH to power off. Zero current when off.

**Wake/sleep flow:**
- **Wake:** Press CON → MCP23008 INT fires → GPIO14 falling edge wakes main core from deep sleep → firmware powers on OLED (GPIO5 LOW) → starts WiFi AP → enters interactive mode
- **Sleep:** 60s inactivity timeout, or navigate to "Sleep" menu item and press CON, or press BAK at top-level menu → firmware powers off OLED (GPIO5 HIGH) → stops WiFi → enters deep sleep

### Piezo Rain ↔ ESP32-C6

| Piezo pin | ESP32-C6 pin | Notes |
|---|---|---|
| VCC (3.3V) | 3.3V (LDO) | Only if op-amp used (v2 circuit) |
| GND | GND | |
| Analog out | GPIO0 (ADC1_CH0) | LP core reads at 5s |

### SIM7080G LTE Modem ↔ ESP32-C6

| Modem pin | ESP32-C6 pin | Silkscreen | Function | Notes |
|---|---|---|---|---|
| VBAT | Raw battery (before LDO) | — | Modem main power | 3.6V Li-SOCl2, LC filter (L1 + 3× 100µF) for TX spikes |
| GND (×2) | GND | GND | Ground | Tie both GND pins to common ground |
| VCC | 3.3V (LDO) | 3V3 | Logic level reference | From HT7333 rail |
| RXD | GPIO16 | 16 (TX) | ESP32 TX → modem RX | UART0, 115200 baud |
| TXD | GPIO17 | 17 (RX) | Modem TX → ESP32 RX | UART0, 115200 baud |
| DTR | GPIO15 | 15 | PSM sleep/wake | HIGH = sleep, LOW = awake. 10kΩ pull-up. |
| PWR | GPIO9 | 9 | Power key | Pulse LOW ≥1s to toggle on/off. 10kΩ pull-up. |
| ANT | SMA → coax → Yagi | — | External antenna | Proxicast 11 dBi Yagi (698–2700 MHz) |

### MicroSD ↔ ESP32-C6

| SD module pin | ESP32-C6 pin | Silkscreen | Notes |
|---|---|---|---|
| VCC (3.3V) | 3.3V (LDO) | 3V3 | Direct 3.3V, no LDO module |
| GND | GND | GND | |
| MOSI | GPIO18 | 18 | |
| MISO | GPIO19 | 19 | |
| SCK | GPIO2 | 2 | |
| CS | GPIO3 | 3 | |

---

## Power Distribution

### Battery → Regulator → All components

```
2× ER34615 Li-SOCl2 D-cell (3.6V, 38 Ah total)
       │
       ├─ [L1 1µH] ─ [C1-C6 300µF] ─ SIM7080G VBAT (LC filter for Cat-M1 TX spikes)
       └── 3.3V LDO (HT7333 or similar, ~1 µA quiescent)
              │
              ├── WindNerd Core VCC (accepts 3.3V)
              ├── ESP32-C6 SuperMini 3V3
              ├── BME280 VCC
              ├── DS3231 VCC
              ├── SIM7080G VCC (logic level reference)
              ├── Piezo rain VCC (if op-amp used)
              └── SD card VCC
```

Modem VBAT draws from raw battery (before LDO) via LC filter. Everything else runs through the 3.3V LDO for wiring simplicity. One rail for all logic.

### Regulator selection

The Li-SOCl2 D-cell nominal voltage is 3.6V, fresh up to 3.67V. The 3.3V LDO drops this to a clean 3.3V for all components.

**LDO:** HT7333 or similar (3.3V, ~1 µA quiescent, SOT-89 package). The HT7333 handles up to 250 mA — our entire system draws < 1 mA average, with brief peaks ~30 mA during SD writes. Plenty of margin.

**Why not direct battery?** Fresh Li-SOCl2 at 3.67V is slightly over spec for 3.3V components (BME280, DS3231, SD card rated 2.97–3.63V). The LDO adds ~1 µA quiescent and solves this cleanly. One rail for everything simplifies wiring.

**Why not buck converter?** At ~0.55 mA average, LDO efficiency is ~92% (3.3/3.6). A buck converter's quiescent (~5-20 µA) would exceed the savings on the logic rail. The modem VBAT path is direct from battery (no regulator). Not worth it.

### Power consumption

| Component | v1 (no op-amp) | v2 (with op-amp) | Notes |
|---|---|---|---|
| WindNerd Core (custom firmware, STOP mode) | ~0.04 mA | ~0.04 mA | |
| ESP32-C6 SuperMini (deep sleep + LP core) | ~0.018 mA | ~0.018 mA | Datasheet figure; actual board may be 2-5× higher (see note below) |
| BME280 (I2C, read every 1 min) | ~0.005 mA | ~0.005 mA | |
| DS3231 RTC (I2C, read every 1 min) | ~0.001 mA | ~0.001 mA | |
| MCP23008 I2C expander (standby) | ~0.001 mA | ~0.001 mA | ~1 µA standby, only active during interactive mode |
| Piezo rain v1 (bias divider only) | ~0.0002 mA | — | 2× 10MΩ divider (~0.16 µA) |
| Piezo rain v2 (OPA376 op-amp) | — | ~0.0011 mA | 0.9 µA op-amp + 0.16 µA divider |
| SD card (write every 1 min) | ~0.01 mA | ~0.01 mA | |
| SIM7080G modem (PSM sleep, 30-min uploads) | ~0.40 mA | ~0.40 mA | 3 µA PSM + board overhead (~50 µA) + 30s TX every 30 min. See [lte-uplink.md](lte-uplink.md). |
| LDO quiescent | ~0.001 mA | ~0.001 mA | |
| Inter-board pull-ups | ~0.01 mA | ~0.01 mA | UART + trigger line + modem DTR/PWR pull-ups |
| **Total from battery** | **~0.55 mA** | **~0.55 mA** | 16× battery headroom over 6 months |

**Deep sleep caveat:** Per [measurements on this exact board](https://dmelo.eu/blog/esp32c6_deepsleep/), deep sleep current is in the **tens of microamps** — higher than the ESP32-C6 datasheet's ~7 µA figure. The onboard LTH7R charger IC and passive components add overhead. If actual ESP32-C6 sleep current is 30 µA instead of 7 µA, ESP32 avg rises to ~0.041 mA and total to ~0.58 mA. Still well within the 38 Ah battery budget (16× headroom). **Measure actual current on the specific board** and update accordingly.

**Modem power caveat:** The SIM7080G's 3 µA PSM is the module-only figure. Breakout board overhead (LDOs, SIM holder, level shifters) pushes realistic sleep to ~10–50 µA. At 30-min upload intervals with ~30s active per upload, the modem adds ~0.40 mA average. See [lte-uplink.md](lte-uplink.md) for detailed power calculations at various upload intervals.

---

## Enclosure considerations

- **IP65+ minimum** — rain and dust proof. IP67 if buried in snow.
- **Cable gland** for anemometer cable entering enclosure
- **Ventilation** — BME280 needs airflow for temp/RH. A small louvered vent or Gore-Tex patch allows humidity exchange without liquid ingress.
- **Radiation shield** — BME280 must not be in direct sun. Either mount it in a Stevenson screen (louvered 3D-printed) or inside the enclosure with a vent.
- **Battery compartment** — Li-SOCl2 D-cell should be accessible for replacement. Separate compartment or accessible lid.
- **Antenna** — ESP32-C6 WiFi antenna should be external if enclosure is metal. If plastic, internal PCB antenna is fine.
- **Size** — everything fits in a ~100×60×40mm enclosure. Small.

---

## Bill of Materials

| Component | Part | Source | Est. cost |
|---|---|---|---|
| Wind sensor + MCU | WindNerd Core kit | [windnerd.net](https://windnerd.net/en/shop) | ~$30-40 |
| Anemometer 3D print | WindNerd 3D files | [GitHub](https://github.com/windnerd-labs/Anemometer-3D-files) (print yourself) | ~$5 filament |
| Datalogger MCU | ESP32-C6 SuperMini | Aliexpress / various | ~$4-6 |
| Temp/RH/pressure | BME280 breakout | Adafruit / Pimoroni / generic | ~$5-10 |
| RTC | DS3231 breakout (with CR1220) | Generic "Tiny RTC" / Adafruit | ~$2-4 |
| Rain sensor | Piezo disc + conditioning circuit (DIY) | Piezo disc + passives | ~$2-5 |
| SD card module | 3.3V SPI microSD breakout (no LDO) | Adafruit / generic | ~$2-5 |
| SD card | 8 GB industrial microSD | Transcend / Kingston / SanDisk | ~$10-15 |
| Battery | 2× ER34615 Li-SOCl2 D-cell (3.6V, 38 Ah total) | Tadiran / Saft / Xeno | ~$20-30 |
| Regulator | 3.3V LDO (HT7333 or similar) | Generic | ~$0.50 |
| Display + UI | 1.3" SH1106 OLED + EC11 encoder + CON/BAK buttons | [Amazon](https://www.amazon.com/MELIFE-Display-Module-Rotary-Encoder/dp/B0GWPRZ283/) | ~$10 |
| I2C expander | MCP23008 8-bit breakout | Adafruit / SparkFun / generic | ~$2-5 |
| LTE modem | SIM7080G Cat-M1 breakout (8-pin) | Ordered by goos | ~$35-50 |
| LTE antenna | Proxicast 11 dBi Yagi (698–2700 MHz) | [Amazon](https://www.amazon.com/Proxicast-Universal-Directional-Antenna-700-2700/dp/B00RJQ8RGC) | ~$35 |
| GNSS antenna | Passive patch antenna, 25×25mm, GPS/GLONASS/Galileo/BeiDou | Various (AliExpress/Amazon) | ~$2 |
| Coax cable | LMR-240, 3–5m, SMA male → SMA male | Various | ~$10-15 |
| Lightning arrestor | SMA coaxial lightning arrestor | Various | ~$15 |
| IoT SIM | 1NCE 10-year IoT SIM (500 MB) | [1NCE](https://1nce.com) | ~$15 |
| Enclosure | IP65+ weatherproof box | Various | ~$5-10 |
| Misc | Wire, headers, resistors, pull-ups, LC filter components | — | ~$3-5 |
| **Total** | | | **~$214-283** |

### Passive components & discrete semiconductors

| Component | Value / Part | Qty | Purpose | Est. cost |
|---|---|---|---|---|
| P-channel MOSFET | AO3401 (SOT-23) or similar | 1 | OLED power gating — gates display VCC, controlled by GPIO5 (firmware) | $0.10 |
| 10kΩ resistor | 10kΩ 0805 or through-hole | 3 | UART RX pull-up (GPIO4), trigger line pull-up (GPIO1), MOSFET gate pull-up (GPIO5) | $0.03 |
| 1N4148 diode | 1N4148 (DO-35 or SOD-323) | 2 | Peak-hold voltage doubler (D1 charge pump, D2 peak detector) | $0.02 |
| 1nF capacitor | 1nF 0805 ceramic (code 102) | 1 | Charge pump cap (C1) | $0.01 |
| 470nF capacitor | 470nF film (low leakage) | 1 | Peak-hold cap (C2) — film dielectric for long hold time | $0.10 |
| 2N7002 MOSFET | 2N7002 (SOT-23) | 1 | Peak-hold cap reset (GPIO8 gate, discharges C2 after ADC read) | $0.03 |
| 10kΩ resistor | 10kΩ 0805 | 1 | Rain ADC series protection (R1) + 1 more for MOSFET gate pulldown (R2) — use 2 from the 10kΩ qty above | $0.01 |
| 10nF capacitor | 10nF 0805 | 1 | Peak detector cap (v2 op-amp circuit, if used) | $0.02 |
| 1µF capacitor | 1µF 0805 ceramic (code 105) | 2 | LDO input + output bypass (one each) | $0.06 |
| Power inductor | 1–2.2 µH, DCR < 0.1Ω, Isat ≥ 2A, SMD 0805/1206 | 1 | SIM7080G VBAT LC filter (L1) — blocks TX spikes from reaching battery | $0.30 |
| 100µF ceramic cap | 100µF 6.3V+ X7R, 0805/1206 | 3 | SIM7080G VBAT bulk caps (C1–C3) — low ESR for Cat-M1 TX bursts | $0.30 |
| 10µF ceramic cap | 10µF 6.3V X7R, 0603 | 1 | SIM7080G VBAT mid-freq bypass (C4) | $0.05 |
| 100nF ceramic cap | 100nF X7R, 0402 | 1 | SIM7080G VBAT high-freq bypass (C5) | $0.02 |
| 33pF ceramic cap | 33pF C0G/NP0, 0402 | 1 | SIM7080G VBAT RF bypass (C6) | $0.02 |
| TVS diode | ~5V standoff, SMA/SMB | 1 | SIM7080G VBAT ESD protection (optional but recommended) | $0.10 |
| 10kΩ resistor | 10kΩ 0805 | 2 | SIM7080G DTR pull-up (GPIO15), PWR pull-up (GPIO9) | $0.02 |
| CR1220 coin cell | CR1220 (primary, non-rechargeable) | 1 | DS3231 RTC backup battery | $0.50 |
| **Subtotal** | | | | **~$0.81** |

**Note on MOSFET:** The AO3401 is a common P-channel MOSFET in SOT-23. Source to 3.3V LDO output, drain to OLED VCC, gate to GPIO5. Firmware controls the gate: HIGH = MOSFET off (OLED unpowered), LOW = MOSFET on (OLED powered). A 10kΩ pull-up on the gate to 3.3V ensures MOSFET stays off during boot/deep sleep. The OLED's I2C lines (SDA/SCL) can stay connected even when VCC is off — the ESP32-C6 I2C pins have internal ESD diodes that won't backfeed significantly at 3.3V.

---

## Programming Setup

### WindNerd Core (STM32G031F8)

- **Tool:** ST-Link V2 dongle (SWD: CLK, DIO, RST, GND)
- **Software:** Arduino IDE + stm32duino board package + WindNerd Core library
- **Board:** Generic STM32G031F8Px
- **Upload method:** STM32CubeProgrammer (SWD)
- **Alternative:** Serial bootloader (jumper CLK→3.3V, use USB-TTL adapter on RX1/TX1)

### ESP32-C6 SuperMini

- **Tool:** USB-C cable (built-in USB, no adapter needed)
- **Software:** Arduino IDE (ESP32 board package) or ESP-IDF or PlatformIO
- **Board:** ESP32C6 SuperMini (various board definitions available)
- **Upload method:** Native USB

---

## Open Questions

1. **Piezo rain sensor** — design confirmed (DIY piezo disc + conditioning circuit). Need to build and test the analog front-end.
2. **Enclosure** — need to source a specific IP65+ box. Size depends on final component layout. Must accommodate modem breakout + antenna feed-through + lightning arrestor.
3. **Radiation shield** — 3D-printed Stevenson screen for BME280, or mount sensor in vented enclosure?
4. **Anemometer mounting** — pole mount height, cable length to enclosure, bearing maintenance interval.
5. **Cold weather** — condensation inside enclosure (desiccant pack?), icing on anemometer (heated variant?), battery insulation. SIM7080G rated -30°C to +80°C — verify breakout board temp range.
6. **All GPIO allocated** — 18 pins used (13 main core + 3 LP core + 2 USB reserved), 3 spare (IO20, IO22, IO23). Encoder + buttons moved to MCP23008 I2C expander (address 0x20) on shared I2C bus. GPIO21 does not exist as a pad on the SuperMini board — this was the root cause for moving encoder/buttons to the expander.
7. **OLED power gating** — display VCC switched via P-channel MOSFET (AO3401), gate controlled by GPIO5 (firmware-driven). 10kΩ pull-up on gate keeps MOSFET off during boot/deep sleep. Zero current when off. Firmware sets GPIO5 LOW to power on OLED after wake, HIGH before returning to sleep.
8. **Onboard LEDs** — GPIO8 (WS2812 RGB) is now used for rain peak-hold reset (2N7002 gate). The WS2812 LED must remain OFF in firmware — do not drive it. GPIO15 (status LED) is now used for SIM7080G DTR — the onboard LED must remain OFF. Desolder WS2812 if its leakage affects sleep current or rain circuit.
9. **Deep sleep current** — board measurements show tens of µA, higher than datasheet. LTH7R charger IC adds overhead. Measure actual current and update power budget.
10. **SIM7080G VBAT sag** — Li-SOCl2 internal resistance (10–50Ω) causes voltage sag during Cat-M1 TX spikes (600 mA). LC filter + 300µF ceramic cap bank mandatory. Test with actual battery + cap. If sag resets the modem, consider Li-ion buffer cell.
11. **AT&T Cat-M1 coverage** — verify Cat-M1 (not just LTE) coverage at the exact deployment site with an AT&T IoT SIM before committing. AT&T's LTE-M footprint is smaller than full LTE.
12. **PSM negotiation** — AT&T must support PSM for 3 µA sleep. AT&T LTE-M supports PSM but negotiated T3324/T3412 timers may limit sleep duration. Test with actual SIM.
13. **1.8V SIM** — SIM7080G requires 1.8V SIM. Most modern IoT SIMs support this, but verify before buying.
14. **GNSS antenna** — SIM7080G needs a separate GNSS antenna for GPS RTC sync. Passive patch (25×25mm) mounted with sky view. Verify breakout board has a GNSS antenna pad. If breakout only has LTE antenna, GPS sync won't work — check before designing enclosure.
15. **GNSS cold fix time** — first GPS fix after deployment takes 30–60s (cold start). Subsequent daily fixes are warm (<5s). If the station is deployed under heavy tree cover or in a valley, fix may fail — DS3231 fallback handles this gracefully.

---

## Next Steps

1. **Clone WindNerd Core repo** — study library source, plan custom firmware
2. **Prototype on breadboard** — WindNerd UART → ESP32-C6, BME280 + DS3231 on I2C, SD on SPI, piezo on ADC, SIM7080G on UART0
3. **Source components** — order BME280, DS3231, SD module, LDO, battery, OLED+encoder, MOSFET, passives, LC filter components, LTE antenna, GNSS antenna, SIM
4. **Write firmware** — WindNerd custom (STOP mode + GPIO trigger) + ESP32-C6 (LP core sampling + main core logging + MQTT uplink via SIM7080G + WiFi retrieval + OLED UI)
5. **Test SIM7080G** — verify AT&T Cat-M1 coverage at site, PSM negotiation, VBAT sag with battery + bulk cap, 1.8V SIM compatibility
6. **Measure actual currents** — verify power budget assumptions, especially ESP32-C6 deep sleep + SIM7080G PSM sleep on actual breakout board
7. **Design enclosure** — 3D-print anemometer + weatherproof box + Stevenson screen + antenna mast mount + lightning arrestor
8. **Cold weather plan** — desiccant, icing, battery insulation, modem temp range verification
9. **Field test** — deploy, verify LTE-M uplink + WiFi retrieval, retrieve data

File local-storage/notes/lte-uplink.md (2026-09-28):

# LTE Modem Options & Power Budget Impact

**Date:** 2026-09-27
**Author:** Coilette (for goos)
**Status:** Research — v2 uplink upgrade path
**Related:** [power-budget.md](power-budget.md), [hardware-design.md](hardware-design.md)

---

## Context

v1 is local-storage only — WiFi soft-AP for spring data retrieval. This document explores adding LTE uplink so the station can phone home during the 6-month deployment instead of waiting for physical retrieval.

**Constraints:**
- USA, AT&T is the only carrier with coverage at the deployment site
- Remote location — needs directional external antenna
- 6 months unattended, battery powered (2× ER34615 Li-SOCl2 D-cell, 38 Ah)
- Current system draws ~0.10 mA avg (without modem)
- Data payload is tiny — wind/rain/env CSV snippets, a few KB per upload

---

## AT&T Network Status (2026)

| Technology | Status on AT&T | Bands | Notes |
|---|---|---|---|
| **LTE-M (Cat-M1)** | ✅ Active, committed long-term | B2, B4, B5, B12, B17, B66 | AT&T's IoT strategy. Low power, PSM/eDRX support. |
| **NB-IoT** | ❌ Sunset Q1 2025 — dead | — | AT&T stopped certifying devices and selling data plans. Do not use. |
| **LTE Cat-1** | ✅ Active | Same as LTE | More power, more bandwidth than needed. |
| **LTE Cat-4** | ✅ Active | Same as LTE | Way too power-hungry for battery IoT. |
| **2G GSM** | ❌ Shutdown complete | — | Dead on AT&T. |
| **3G** | ❌ Shutdown Feb 2022 | — | Dead on AT&T. |

**Key takeaway:** LTE-M (Cat-M1) is the only viable low-power option on AT&T. NB-IoT is dead. Cat-1 and Cat-4 work but burn 10-100× more power.

### AT&T LTE Bands at the Site

AT&T's rural coverage backbone is **700 MHz (Band 12/17)** — longest range, best penetration. Secondary rural band is **850 MHz (Band 5)**. Higher bands (1900 MHz B2, 1700 MHz B4/66, 2300 MHz B30) are urban/suburban capacity layers with shorter range.

| Band | Frequency | Range | Penetration | AT&T rural? |
|---|---|---|---|---|
| B12/B17 | 700 MHz | Excellent | Excellent | ✅ Primary |
| B5 | 850 MHz | Very good | Very good | ✅ Secondary |
| B2 | 1900 MHz | Moderate | Moderate | ❌ Urban |
| B4/B66 | 1700 MHz (AWS) | Moderate | Moderate | ❌ Urban |
| B30 | 2300 MHz (WCS) | Short | Poor | ❌ Urban |

**Antenna must cover 700 MHz (B12/17) and ideally 850 MHz (B5).** Higher bands are bonus if the tower has them, but 700 MHz is what reaches remote sites.

---

## Modem Options Compared

### 1. SIM7080G — Cat-M1 + NB-IoT (BEST FIT)

| Spec | Value |
|---|---|
| LTE class | Cat-M1 (eMTC) + NB-IoT |
| Max downlink/uplink | 0.3 / 0.37 Mbps (Cat-M1) |
| Sleep current (PSM) | **~3 µA** |
| Active current (Cat-M1 TX) | ~200–600 mA peaks |
| Idle/connected current | ~3–10 mA |
| Bands (global "G" variant) | B1, B2, B3, B4, B5, B8, B12, B13, B18, B19, B20, B25, B26, B27, B28, B66, B71, B85 |
| AT&T bands supported | B2, B4, B5, B12, B17 (via B12), B66, B71 |
| GNSS | GPS, GLONASS, Galileo, BeiDou |
| Host interface | UART, USB |
| SIM voltage | 1.8 V only |
| Form factors | LGA module, Waveshare HAT, breakout boards |
| Price (Waveshare HAT) | ~$35–50 |

**Why it fits:** 3 µA PSM sleep is the lowest in the category. Cat-M1 is AT&T's committed IoT technology. NB-IoT is dead on AT&T but the modem falls back to Cat-M1 seamlessly. GNSS is used for daily DS3231 RTC sync — eliminates ±5 min drift over 6 months.

**Catch:** 1.8 V SIM only. Need a 1.8 V-compatible IoT SIM. Most modern M2M SIMs support 1.8 V, but verify before buying.

### 2. SIM7000G — Cat-M1 + NB-IoT (ALTERNATIVE)

| Spec | Value |
|---|---|
| LTE class | Cat-M1 + NB-IoT |
| Sleep current (PSM) | ~7.4 µA (module only) |
| Board-level sleep (LilyGo T-SIM7000G) | **~1.2 mA** (board overhead!) |
| Active current | ~200–600 mA peaks |
| Bands (global "G" variant) | B1, B2, B3, B4, B5, B8, B12, B13, B18, B19, B20, B25, B26, B27, B28, B66, B71, B85 |
| AT&T bands | Same as SIM7080G |
| GNSS | GPS, GLONASS, Galileo, BeiDou |
| Form factors | Botletics Arduino shield, LilyGo all-in-one, breakout |
| Price (Botletics shield) | ~$40–60 |

**Why it's #2:** Same Cat-M1 capability, but module sleep is 2.5× higher than SIM7080G (7.4 µA vs 3 µA). On a breakout board (Botletics, LilyGo), board-level quiescent (LDOs, level shifters, SIM holder) pushes actual sleep to ~1.2 mA — 400× the module's PSM rating. The SIM7080G has the same board overhead problem but starts lower.

**Botletics advantage:** Best documentation and library support in the category. If you're learning, start here. For production low-power, SIM7080G wins.

### 3. A7670G — LTE Cat-1 (MORE POWER, MORE BANDWIDTH)

| Spec | Value |
|---|---|
| LTE class | Cat-1 (10/5 Mbps) |
| Sleep current | ~1–5 mA (module, no PSM) |
| Active current | ~300–800 mA peaks |
| 2G fallback | Yes (GSM/GPRS) |
| Form factors | LilyGo T-A7670G (ESP32 + modem + GPS + 18650) |
| Price (LilyGo board) | ~$25–40 |

**Why not:** Cat-1 has no PSM (Power Saving Mode). The modem can't drop to microamps — best case is ~1 mA sleep with DTR asserted. For a 6-month battery deployment, that's 4.4 Ah just for modem sleep. Doable with 38 Ah battery, but wasteful when Cat-M1 needs 0.003 Ah for the same job.

**Use case:** If you need more bandwidth (firmware OTA, images, frequent large uploads) and have solar or wall power. Not our case.

### 4. SIM7600G-H — LTE Cat-4 (OVERKILL)

| Spec | Value |
|---|---|
| LTE class | Cat-4 (150/50 Mbps) |
| Sleep current | ~1 mA (best case, DTR sleep) |
| Active current | Up to **2 A** transmit spikes |
| Board-level sleep (LilyGo) | ~1–5 mA (measured) |
| Price (Waveshare HAT) | ~$40–60 |

**Why not:** Cat-4 transmit spikes hit 2 A. The Li-SOCl2 D-cells can't deliver 2 A — they're rated for ~100 mA continuous max. You'd need a separate Li-ion battery + charger for the modem alone. Absurd overkill for sending a few KB of weather data.

### 5. nRF9151 / nRF9160 — Nordic Cat-M1 (ALT ECOSYSTEM)

| Spec | Value |
|---|---|
| LTE class | Cat-M1 + NB-IoT |
| Sleep current | ~3–9 µA (PSM) |
| Architecture | Nordic nRF91 SoC (ARM Cortex-M33 + LTE modem) |
| Use mode | Flash with "atclient" firmware → UART AT modem passthrough |
| Price | ~$30–50 (dev board) |

**Why not:** Different ecosystem from ESP32. The nRF91 is a combined MCU + modem — you'd either replace the ESP32-C6 entirely or use it as a dumb AT modem (wasteful, and the toolchain is completely different). Interesting for a clean-sheet design, but we already have ESP32-C6 + firmware investment.

---

## Power Budget With LTE

### Strategy: Infrequent Uploads with PSM Sleep

The modem stays in PSM (Power Saving Mode) between uploads. ESP32-C6 wakes it via GPIO, opens UART, sends buffered data as a compact packet (MQTT or HTTP POST), then commands the modem back to PSM. The modem stays registered to the network during PSM — reconnection takes seconds, not the 30-60s of a cold attach.

**Upload payload:** Compressed CSV snippet. 5s wind + rain for 10 min = 120 rows × ~30 bytes = ~3.6 KB. Env data for 10 min = 10 rows × ~40 bytes = 400 bytes. Total per upload: ~4 KB. Trivial even for Cat-M1's 0.3 Mbps.

### Power Calculation: SIM7080G at Various Upload Intervals

**Module-only sleep (3 µA PSM):**

| Upload interval | Sleep energy | Upload energy | Avg current | 6-month Ah | % of 38 Ah battery |
|---|---|---|---|---|---|
| 10 min | 0.003 mA × 9.5 min | ~300 mA × 30s attach+TX | ~1.0 mA | 4.4 Ah | 12% |
| 30 min | 0.003 mA × 29.5 min | ~300 mA × 30s | ~0.35 mA | 1.5 Ah | 4% |
| 1 hour | 0.003 mA × 59.5 min | ~300 mA × 30s | ~0.18 mA | 0.79 Ah | 2% |
| 2 hours | 0.003 mA × 119.5 min | ~300 mA × 30s | ~0.09 mA | 0.40 Ah | 1% |
| 6 hours | 0.003 mA × 359.5 min | ~300 mA × 30s | ~0.03 mA | 0.13 Ah | 0.3% |

**Upload energy model:** 30s per upload = ~5s network wake from PSM + ~10s attach + ~10s TLS+MQTT publish + ~5s teardown. Average current during upload ~300 mA (Cat-M1 TX burst averaged over the session, not peak).

### Realistic Board-Level Sleep (the gotcha)

Module PSM is 3 µA. But breakout boards add:
- LDO quiescent: ~1–5 µA
- SIM holder leakage: ~1 µA
- Level shifters: ~1–5 µA
- LED indicators (if not removed): ~200–500 µA each
- Board trace leakage: negligible

**Realistic board sleep: ~10–50 µA** (with LEDs removed). Still excellent.

| Scenario | Board sleep | Upload interval | Total avg current (system + modem) | 6-month Ah |
|---|---|---|---|---|
| Optimistic (10 µA board sleep) | 10 µA | 30 min | 0.10 + 0.36 = **0.46 mA** | 2.0 Ah |
| Realistic (50 µA board sleep) | 50 µA | 30 min | 0.10 + 0.40 + 0.052 = **0.55 mA** | 2.4 Ah |
| Realistic (50 µA board sleep) | 50 µA | 1 hour | 0.10 + 0.23 = **0.33 mA** | 1.4 Ah |
| Realistic (50 µA board sleep) | 50 µA | 2 hours | 0.10 + 0.14 = **0.24 mA** | 1.1 Ah |
| Pessimistic (1.2 mA board sleep, LilyGo-level) | 1.2 mA | 1 hour | 0.10 + 1.38 = **1.48 mA** | 6.5 Ah |

**Even the pessimistic case (1.2 mA board sleep, hourly uploads) fits in 38 Ah with 5.8× headroom.** The realistic case (50 µA sleep, 30-min uploads) uses 2.2 Ah — 5.7% of battery capacity over 6 months.

### Comparison: All Modems at 30-min Upload Interval

| Modem | Board sleep | Avg current (system + modem) | 6-month Ah | Verdict |
|---|---|---|---|---|
| SIM7080G (realistic board) | 50 µA | 0.55 mA | 2.4 Ah | ✅ Best |
| SIM7080G (pessimistic board) | 1.2 mA | 1.65 mA | 7.2 Ah | ✅ OK |
| SIM7000G (Botletics, measured) | 1.2 mA | 1.65 mA | 7.2 Ah | ✅ OK |
| A7670G (Cat-1, no PSM) | ~1 mA | 1.45 mA | 6.3 Ah | ⚠️ Wasteful |
| SIM7600G-H (Cat-4) | ~1 mA | 1.45 mA | 6.3 Ah | ❌ 2A TX spikes kill it |

All Cat-M1 options fit the battery. The difference is headroom — SIM7080G gives 16× headroom (including daily GPS sync), SIM7000G gives 5×. Cat-1/Cat-4 technically fit but TX spikes are a battery-delivery problem, not just capacity.

---

## Antenna Selection

### Requirements

- **Must cover:** 700 MHz (AT&T B12/17) — primary rural coverage
- **Should cover:** 850 MHz (AT&T B5) — secondary rural
- **Nice to have:** 1700/1900/2300 MHz (AT&T B2/B4/B66/B30) — if tower has them
- **Type:** Directional (Yagi or log-periodic) — aim at nearest AT&T tower
- **Gain:** 9–11 dBi (enough to pull weak signal without overdriving the modem)
- **Mounting:** Outdoor, mast-mounted, weatherproof
- **Connector:** SMA (most common on modem breakouts) or TS-9 (some boards)

### Recommended Antennas

| Antenna | Type | Freq range | Gain | Connector | Price | Notes |
|---|---|---|---|---|---|---|
| **Proxicast 11 dBi Yagi** | Log-periodic Yagi | 698–2700 MHz | 11 dBi | SMA male | ~$35 | Covers all AT&T LTE bands. Amazon. Best all-rounder. |
| **RFMAX RY-4-14-SNF** | 9-element Yagi | 615–6100 MHz | ~9 dBi | N-female | ~$60 | Rugged outdoor, covers B71 (600MHz) too. Overkill but future-proof. |
| **Tupavco TP514** | Log-periodic Yagi | 806–960 MHz + 1.7–2.5 GHz | 9 dBi | SMA + TS-9 adapter | ~$25 | Cheapest option. Covers 850+1700/1900 but **misses 700 MHz**. Only buy if site has strong B5 signal. |
| **Generic 700/800/850/900 Yagi** (eBay) | Yagi | 700–960 MHz | ~8–10 dBi | SMA | ~$20 | Covers 700+850 MHz. Cheap. Misses higher bands but those don't reach remote sites anyway. |

**Recommendation:** Proxicast 11 dBi (698–2700 MHz). Covers 700 MHz (critical) through 2700 MHz (all AT&T bands), $35, well-reviewed, outdoor rated. If on a budget, the generic 700–960 MHz Yagi from eBay works — 700 MHz is what matters at remote sites.

### Antenna Installation Notes

- **Aim at nearest AT&T tower** — use [CellMapper.net](https://www.cellmapper.net) or OpenSignal to find tower location and AT&T band info
- **Height matters** — mount on mast above tree line if possible. 700 MHz bends over terrain better than higher freqs, but line-of-sight still wins
- **Cable loss** — keep coax short. At 700 MHz, RG58 loses ~3 dB per 10m. Use LMR-240 or LMR-400 for runs >3m. Or mount a preamp near the antenna
- **Polarity** — LTE uses ±45° slant polarization (X-pol). Match the antenna's polarity or use a dual-pol antenna. Most Yagis are vertical; that's close enough for a fixed installation
- **Lightning protection** — outdoor antenna = lightning target. Use a coaxial lightning arrestor at the entry point, bond to ground

---

## SIM Card & Data Plan

### Requirements
- **Must support LTE-M (Cat-M1)** on AT&T
- **1.8 V SIM** (SIM7080G requirement) — most modern IoT SIMs support this
- **IoT/M2M plan** — not a voice SIM. Data-only.

### Recommended Providers

| Provider | Plan | Price | Notes |
|---|---|---|---|
| **Hologram.io** | IoT SIM, pay per MB | $0.60/MB, $5/mo base | Global roaming, LTE-M supported. Best for prototyping. ~4 KB/upload × 144 uploads/day = 576 KB/day ≈ $0.35/day. |
| **1NCE** | 10-year IoT SIM | ~$15 one-time for 500 MB | Flat rate, no monthly. 500 MB lasts years at our data rate. Best value. |
| **AT&T IoT** | AT&T IoT Data Plans | Varies ($1–25/mo) | Direct from AT&T. Best coverage guarantee but more expensive. |
| **Twilio Super SIM** | Pay per MB | $0.50/MB | Developer-friendly API. LTE-M supported. |

**Recommendation:** 1NCE 10-year SIM. 500 MB for ~$15 one-time. At 4 KB/upload every 30 min, that's 576 KB/day = 105 MB/year. 500 MB lasts ~4.7 years. No monthly fee. Perfect for a 6-month deployment.

### Data Volume Check

| Upload interval | Data per upload | Uploads/day | Data/day | Data/6 months |
|---|---|---|---|---|
| 10 min | ~4 KB | 144 | 576 KB | 103 MB |
| 30 min | ~4 KB | 48 | 192 KB | 34 MB |
| 1 hour | ~4 KB | 24 | 96 KB | 17 MB |
| 2 hours | ~4 KB | 12 | 48 KB | 8.6 MB |

Even 10-minute uploads fit in 500 MB. 30-minute uploads use 34 MB over 6 months — nothing.

---

## Integration with ESP32-C6

### Wiring (SIM7080G breakout → ESP32-C6)

| SIM7080G pin | ESP32-C6 pin | Function |
|---|---|---|
| VBAT | Raw battery (before LDO, via LC filter) | Power — 3.6V Li-SOCl2, L1 1µH + 3× 100µF |
| VCC | 3.3V (LDO output) | Logic level reference |
| GND (×2) | GND | Ground — tie both to common ground |
| RXD | GPIO16 (UART0 TX) | ESP32 TX → Modem RX |
| TXD | GPIO17 (UART0 RX) | Modem TX → ESP32 RX |
| DTR | GPIO15 | Sleep/wake control (PSM). 10kΩ pull-up. |
| PWR | GPIO9 | Power key. 10kΩ pull-up. |
| ANT | SMA connector → coax → Yagi | External antenna |

**Free pins after allocation:** 20, 22, 23 (3 spare). The modem uses GPIO9 (PWR), GPIO15 (DTR), GPIO16 (UART0 TX), GPIO17 (UART0 RX).

**Note:** SIM7080G wants 3.8V VBAT typically. The Li-SOCl2 battery is 3.6V nominal. A boost converter or separate LDO from the raw battery may be needed. Check the specific breakout board's input range — some accept 3.3–5V and regulate internally.

### Firmware Flow

```
Every 30 min (main core wake):
1. Wake modem from PSM (assert DTR)
2. Wait for "OK" on UART
3. Open MQTT connection (or HTTP POST)
4. Send buffered CSV data from SD card
5. Close connection
6. Command modem to PSM (AT+CFUN=0 or AT+CPSMS=1)
7. Deassert DTR
8. Main core back to deep sleep
```

The LP core continues 5s wind sampling during modem activity — the two are independent. The modem upload happens on the main core's 1-minute wake cycle (piggyback on the BME280/SD flush wake).

### Upload Protocol

| Protocol | Pros | Cons | Use for v2? |
|---|---|---|---|
| **MQTT** | Lightweight, persistent session, QoS levels | Needs broker (self-hosted or cloud) | ✅ Best — publish to a broker, home station subscribes |
| HTTP POST | Simple, RESTful | Heavier (TLS handshake overhead) | Fallback |
| CoAP | Ultra-lightweight | Less tooling, NAT issues | Skip |
| SMS | No data connection needed | 160 chars, AT&T SMS fees, unreliable delivery | Emergency alerts only |

**Recommendation:** MQTT to a self-hosted broker (Mosquitto on the home station or a $5 VPS). ESP32-C6 publishes to `weathernerd/station-id/wind`, `weathernerd/station-id/env`, `weathernerd/station-id/rain`. Home station or VPS subscribes and stores to database.

---

## Impact on v1 Power Budget

| Scenario | Avg current | 6-month Ah | % of 38 Ah | Headroom |
|---|---|---|---|---|
| **v1 (no LTE)** | 0.10 mA | 0.44 Ah | 1.2% | 86× |
| **v2 + SIM7080G, 30-min upload + daily GPS sync (realistic)** | 0.55 mA | 2.4 Ah | 6.3% | 16× |
| **v2 + SIM7080G, 1-hour upload (realistic)** | 0.33 mA | 1.4 Ah | 3.7% | 27× |
| **v2 + SIM7080G, 2-hour upload (realistic)** | 0.24 mA | 1.1 Ah | 2.9% | 35× |
| **v2 + SIM7000G, 30-min upload (pessimistic board)** | 1.65 mA | 7.2 Ah | 19% | 5× |
| **v2 + A7670G Cat-1, 30-min upload** | 1.45 mA | 6.3 Ah | 17% | 6× |

**Verdict:** LTE-M with SIM7080G at 30-min or 1-hour uploads + daily GPS sync is comfortably within the 38 Ah battery. Even with pessimistic board overhead, 6-month runtime is fine. The 2× D-cell battery was sized for 80× headroom without modem — LTE + GPS eats into that headroom but 16× is still massive.

**Solar still not needed.** Even the worst realistic case (7.2 Ah) leaves 30.8 Ah unused. The battery was massively oversized for v1; LTE is what makes the oversizing justified.

---

## Bill of Materials (v2 LTE Add-on)

| Item | Part | Price | Notes |
|---|---|---|---|
| Modem board | Waveshare SIM7080G Cat-M/NB-IoT HAT (or equivalent breakout) | ~$35–50 | UART-controlled, PSM capable |
| Antenna | Proxicast 11 dBi Yagi (698–2700 MHz) | ~$35 | Outdoor directional, covers all AT&T bands |
| Coax cable | LMR-240, 3–5m, SMA male → SMA male | ~$10–15 | Keep short to minimize loss |
| Lightning arrestor | SMA coaxial lightning arrestor | ~$15 | Outdoor install safety |
| SIM card | 1NCE 10-year IoT SIM (500 MB) | ~$15 | One-time, no monthly fee |
| Mounting hardware | Mast, U-bolts, weatherproofing | ~$15 | |
| **Total** | | **~$125–140** | |

---

## Recommendation

| Decision | Choice | Reason |
|---|---|---|
| **Modem** | SIM7080G | 3 µA PSM sleep, Cat-M1 on AT&T, global bands, GNSS for RTC sync |
| **Upload interval** | 30 min (default), configurable down to 10 min | 30 min = 2.4 Ah/6mo, 16× battery headroom. 10 min if real-time matters. |
| **Antenna** | Proxicast 11 dBi Yagi (698–2700 MHz) | Covers 700 MHz (critical) + all AT&T bands, $35, outdoor rated |
| **GNSS antenna** | Passive patch, 25×25mm, ~$2 | For daily GPS RTC sync. Mounted with sky view. |
| **SIM** | 1NCE 10-year (500 MB, ~$15) | No monthly fee, 500 MB lasts years at our data rate |
| **Protocol** | MQTT to self-hosted broker | Lightweight, persistent, QoS. Home station or VPS subscribes. |
| **RTC sync** | Daily GPS fix via SIM7080G GNSS | Eliminates DS3231 drift. ~45s fix once/day, negligible power cost. |
| **v1 or v2?** | v1 — folded in | SIM7080G is part of v1 build. |

### What This Does NOT Change

- WindNerd custom firmware — unaffected, still STOP mode + on-demand
- ESP32-C6 LP core — still handles 5s wind sampling, modem is main-core only
- SD card — still primary storage, LTE is secondary uplink
- WiFi soft-AP — still used for spring data retrieval (full CSV download)
- Battery — 2× ER34615 Li-SOCl2 D-cell (38 Ah), no solar needed
- OLED + encoder + buttons — still for interactive mode, unaffected. Encoder + buttons now on MCP23008 I2C expander, only INT line uses GPIO14.
- DS3231 RTC — still the always-on clock; GPS corrects drift daily, CR1220 backup still needed

### What Changes

- 4 GPIO pins for modem UART + control (GPIO 9, 15, 16, 17)
- Firmware: main core wakes modem every 30 min, sends MQTT, sleeps. Daily GPS sync cycle corrects DS3231.
- Power budget: 0.10 → 0.55 mA avg (still 16× battery headroom)
- Enclosure: LTE antenna feed-through + lightning arrestor + GNSS patch antenna with sky view
- BOM: +$127 for modem + LTE antenna + GNSS antenna + SIM

---

## Open Questions

1. **SIM7080G breakout board availability** — Waveshare HAT is Pi-oriented. Need a bare breakout or SIMCom dev board with UART + SMA. Check availability of SIM7080G on a simple carrier.
2. **Modem power supply** — SIM7080G wants 3.8V VBAT. Li-SOCl2 is 3.6V. Boost converter adds quiescent current. Or run from the 3.3V LDO and accept slightly reduced TX power. Test signal strength.
3. **AT&T Cat-M1 coverage at the exact site** — AT&T's LTE-M footprint is smaller than their full LTE footprint. Verify with an AT&T IoT SIM + phone test before committing. [AT&T IoT coverage map](https://www.business.att.com/products/lpwa.html).
4. **PSM negotiation** — AT&T must support PSM for the modem to enter 3 µA sleep. AT&T LTE-M network supports PSM but the negotiated T3324/T3412 timers may limit sleep duration. Test with actual SIM.
5. **Cold weather** — modem spec is typically -30°C to +80°C. Li-SOCl2 is rated -55°C. The modem should survive winter, but verify the specific breakout board's temperature rating.

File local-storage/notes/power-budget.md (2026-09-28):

# Remote Wind Monitoring Station — Power Budget

**Date:** 2026-09-22
**Author:** Coilette (for goos)
**Status:** Updated — SIM7080G LTE-M uplink folded into v1
**Related:** [storage-budget.md](storage-budget.md)

---

## Architecture (locked)

- **Wind sensing:** WindNerd Core (STM32G031F8) — **custom firmware**, sleeps until ESP32 requests data
- **Datalogger + sensors:** ESP32-C6 SuperMini — triggers WindNerd on demand, reads BME280 (I2C) + DS3231 RTC (I2C) + piezo rain (ADC), writes to SD card
- **RTC:** DS3231 (TCXO, ±2 ppm, CR1220 backup) on shared I2C with BME280
- **Storage:** MicroSD card (industrial, FAT32, daily CSV files — two streams: wind/rain at 5s, temp/RH/pressure at 1 min)
- **Sample rate:** 5 seconds (wind + rain), 1 minute (temp/RH/pressure)
- **Data retrieval:** SIM7080G LTE-M MQTT uplink (30-min intervals) + ESP32 WiFi soft-AP for full CSV download on retrieval
- **Display + UI:** SH1106 1.3" OLED + EC11 rotary encoder + CON/BAK buttons on shared I2C + GPIO. Power-gated via MOSFET (GPIO5) — zero current in sleep. Only active when CON button wakes the main core.
- **No chip swaps.** STM32G031F8 stays as-is with custom firmware. ESP32-C6 handles everything beyond wind.

### Board: ESP32-C6 SuperMini

Selected from available boards (ESP32-C3 SuperMini, ESP32-C6 SuperMini, Xiao ESP32-C3).

| Factor | ESP32-C6 SuperMini | ESP32-C3 SuperMini | Xiao ESP32-C3 |
|---|---|---|---|
| Low-power coprocessor | ✅ LP RISC-V core | ❌ None | ❌ None |
| Deep sleep current | ~5-7 µA | ~5 µA | ~5 µA |
| WiFi | WiFi 6 (better range, lower power) | WiFi 4 | WiFi 4 |
| BLE | BLE 5.3 | BLE 5.0 | BLE 5.0 |
| Flash | 4 MB | 4 MB | 4 MB |
| GPIO available | 22 (silkscreen 0–9, 12–15, 16/TX, 17/RX, 18–23) | ~11 | More (Xiao form factor) |
| Onboard LiPo charging | ❌ | ❌ | ✅ (adds quiescent) |

**The LP core is the deciding factor.** Our entire power budget relies on a low-power coprocessor handling the 5s sampling loop while the main core sleeps. Without it (C3), the main core must wake every 5s, roughly doubling ESP32 power consumption.

| | ESP32-C6 (LP core) | ESP32-C3 (no LP core) |
|---|---|---|
| Main core wake frequency | Every 1 min | Every 5s |
| ESP32 avg current | ~0.155 mA | ~0.4–0.5 mA |
| Total system avg | ~0.24 mA | ~0.5–0.6 mA |

WiFi 6 also gives better range for the spring data-retrieval workflow — press CON button, connect, download CSVs.

### GPIO allocation (18 pins used, 22 available, 3 free)

| Function | Pins | Silkscreen |
|---|---|---|
| ADC (piezo rain) | 1 | 0 |
| WindNerd trigger (output) | 1 | 1 |
| UART RX from WindNerd | 1 | 4 |
| I2C (BME280 + DS3231 + OLED: SDA + SCL) | 2 | 6, 7 |
| SPI (SD card: MOSI + MISO + SCK + CS) | 4 | 2, 3, 18, 19 |
| MCP23008 I2C expander INT | 1 | 14 |
| OLED VCC MOSFET gate | 1 | 5 |
| Rain peak-hold reset (2N7002 gate) | 1 | 8 |
| SIM7080G UART (TX + RX) | 2 | 16, 17 |
| SIM7080G DTR (PSM control) | 1 | 15 |
| SIM7080G PWR (power key) | 1 | 9 |
| **Total** | **18** | |

3 free (IO20, IO22, IO23). Encoder + buttons moved to MCP23008 I2C expander (address 0x20) on shared I2C bus. MCP23008 INT → GPIO14 wakes ESP32 on any pin change. GPIO10/GPIO11 don't exist on SuperMini. GPIO21 does not exist as a pad on the SuperMini board.

---

## WindNerd Core — Custom Firmware
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

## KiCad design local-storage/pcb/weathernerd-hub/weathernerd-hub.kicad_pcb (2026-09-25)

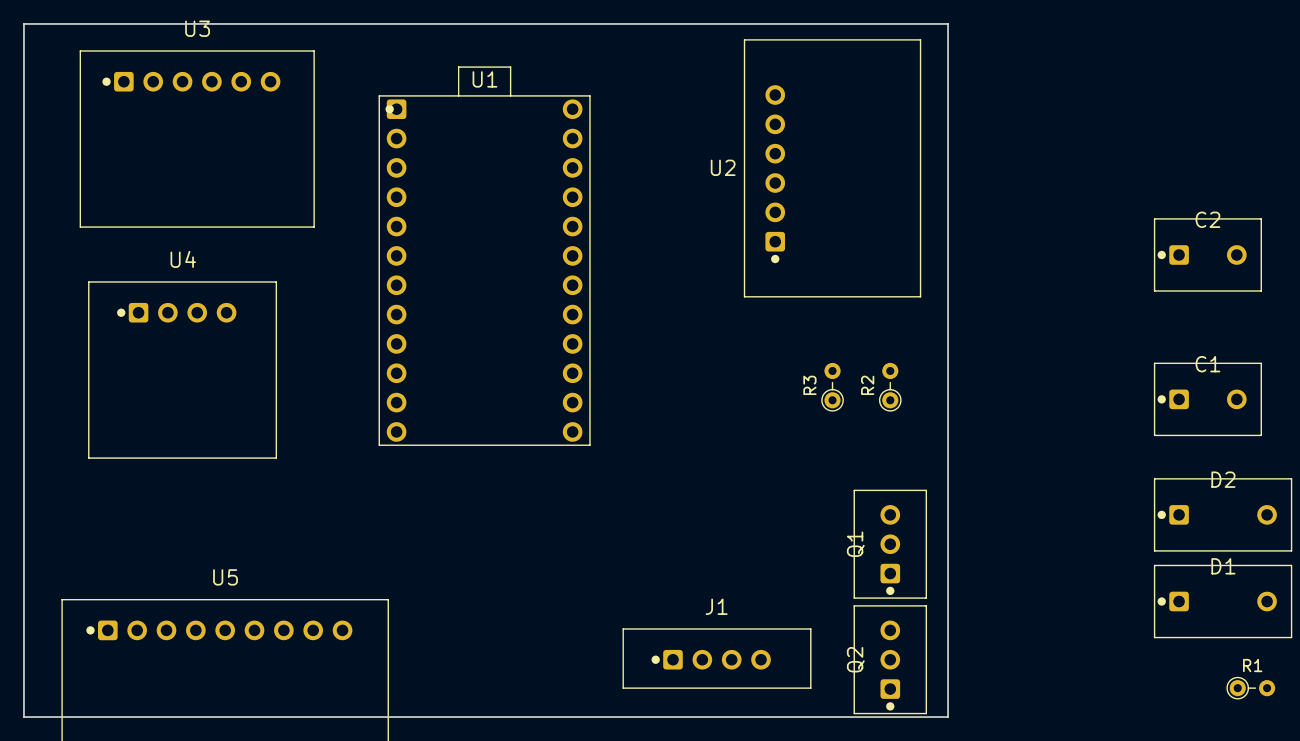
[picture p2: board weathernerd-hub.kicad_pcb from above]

Board: 2 copper layers, 80.0 x 60.0 mm, 15 parts (0 on the bottom side), 18 nets, no tracks yet.

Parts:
C1: 1nF; C1
C2: 470nF; C2
D1: 1N4148; D1
D2: 1N4148; D2
J1: WindNerd-Conn
Q1: 2N7002; Q1
Q2: AO3401; Q2
R1, R2, R3: 10k; R_Axial_DIN0204_L3.6mm_D1.6mm_P2.54mm_Vertical
U1: ESP32-C6-SuperMini
U2: MicroSD-SPI
U3: BME280
U4: DS3231
U5: OLED-Encoder-Btns

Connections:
+3V3: J1.VCC, Q2.S, R3.2, U1.3V3, U2.3V3, U3.VCC, U4.VCC
BAK_BTN: U1.23 (IO23), U5.BAK
CON_BTN: U1.22 (IO22), U5.CON
ENC_A: U1.14 (IO14), U5.TRA
ENC_B: U1.20 (IO20), U5.TRB
GND: C2.2, J1.GND, Q1.S, R2.2, U1.GND, U2.GND, U3.GND, U4.GND, U5.GND
I2C_SCL: U1.7 (IO7), U3.SCL, U4.SCL, U5.SCL
I2C_SDA: U1.6 (IO6), U3.SDA, U4.SDA, U5.SDA
OLED_GATE: Q2.G, R3.1, U1.5 (IO5)
OLED_PWR: Q2.D, U5.VCC
PEAK: C2.1, Q1.D, R1.1
RAIN_ADC: R1.2, U1.0 (IO0)
RAIN_RST: Q1.G, R2.1, U1.8 (IO8)
SPI_CS: U1.3 (IO3), U2.CS
SPI_MISO: U1.19 (IO19), U2.MISO
SPI_MOSI: U1.18 (IO18), U2.MOSI
WIND_TRIG: J1.TRG, U1.1 (IO1)
WIND_TX: J1.RX, U1.4 (IO4)

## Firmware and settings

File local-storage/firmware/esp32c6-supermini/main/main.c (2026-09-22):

/*
 * WeatherNerd ESP32-C6 SuperMini — Main core firmware
 *
 * Main core responsibilities:
 * - On boot: init I2C bus, LP UART, LP core, rain ADC, DS3231, BME280, enter deep sleep
 * - On LP core wakeup (every 1 min): read DS3231 + rain ADC + BME280, flush to SD
 * - On GPIO22 wakeup (CON button): power on OLED, run interactive UI menu
 *
 * Note: ESP32-C6 LP core has no LP ADC. Rain ADC is read by the main core
 * on its 1-minute wake cycle using the HP ADC peripheral.
 */

#include <stdio.h>
#include <stdlib.h>
#include <string.h>
#include <time.h>
#include <unistd.h>
#include "esp_sleep.h"
#include "esp_err.h"
#include "esp_log.h"
#include "ulp_lp_core.h"
#include "lp_core_main.h"
#include "lp_core_uart.h"
#include "driver/gpio.h"
#include "freertos/FreeRTOS.h"
#include "freertos/task.h"
#include "esp_adc/adc_oneshot.h"
#include "esp_adc/adc_cali.h"
#include "esp_adc/adc_cali_scheme.h"
#include "storage.h"
#include "i2c_bus.h"
#include "ds3231.h"
#include "bme280.h"
#include "oled.h"
#include "ui.h"

static const char *TAG = "weathernerd";

/* LP core binary symbols */
extern const uint8_t lp_core_main_bin_start[] asm("_binary_lp_core_main_bin_start");
extern const uint8_t lp_core_main_bin_end[]   asm("_binary_lp_core_main_bin_end");

/* Pin assignments */
#define CON_BUTTON_GPIO     22   /* CON button — wake interrupt + UI confirm */
#define OLED_MOSFET_GPIO    5    /* P-channel MOSFET gate for OLED power */
#define RAIN_ADC_UNIT       ADC_UNIT_1
#define RAIN_ADC_CHANNEL    ADC_CHANNEL_0  /* GPIO0 = ADC1_CH0 */
#define RAIN_RESET_GPIO     8              /* 2N7002 gate — discharges 470nF peak-hold cap */

/* Main core wake interval (1 minute) */
#define MAIN_WAKE_INTERVAL_US  (60 * 1000 * 1000)

/* ---- Peripherals ---- */
static adc_oneshot_unit_handle_t s_adc_handle = NULL;
static i2c_master_dev_handle_t s_ds3231_dev = NULL;
static i2c_master_dev_handle_t s_bme280_dev = NULL;
static i2c_master_dev_handle_t s_oled_dev = NULL;

/* ---- Rain ADC ---- */

static void init_rain_adc(void)
{
    adc_oneshot_unit_init_cfg_t init_cfg = {
        .unit_id = RAIN_ADC_UNIT,
    };
    ESP_ERROR_CHECK(adc_oneshot_new_unit(&init_cfg, &s_adc_handle));

    adc_oneshot_chan_cfg_t chan_cfg = {
        .atten = ADC_ATTEN_DB_12,
        .bitwidth = ADC_BITWIDTH_12,
    };
    ESP_ERROR_CHECK(adc_oneshot_config_channel(s_adc_handle, RAIN_ADC_CHANNEL, &chan_cfg));

    /* GPIO8 — 2N7002 gate to discharge 470nF peak-hold cap after each read.
     * LOW = MOSFET OFF (cap holds peak). HIGH = MOSFET ON (cap discharges).
     * 10kΩ pulldown ensures OFF during deep sleep. */
    gpio_set_direction(RAIN_RESET_GPIO, GPIO_MODE_OUTPUT);
    gpio_set_level(RAIN_RESET_GPIO, 0);

    ESP_LOGI(TAG, "Rain ADC initialized (ADC1_CH0 / GPIO0, reset on GPIO8)");
}

/* Read peak-hold cap: burst-read 16 samples (~2ms), take max, then discharge cap.
 * The 470nF film cap holds the highest raindrop impact voltage since the last
 * reset. 1N4148 reverse leakage (~5nA) gives a hold time well beyond 60s.
 * After reading, pulse GPIO8 HIGH for 5ms to discharge C2 for a clean window. */
static uint16_t read_rain_adc(void)
{
    int raw = 0, max_raw = 0;
    for (int i = 0; i < 16; i++) {
        esp_err_t ret = adc_oneshot_read(s_adc_handle, RAIN_ADC_CHANNEL, &raw);
        if (ret == ESP_OK && raw > max_raw) {
            max_raw = raw;
        }
    }

    /* Discharge peak-hold cap for next interval */
    gpio_set_level(RAIN_RESET_GPIO, 1);
    usleep(5000);   /* 5ms — full discharge of 470nF through 2N7002 */
    gpio_set_level(RAIN_RESET_GPIO, 0);

    return (uint16_t)max_raw;
}

/* ---- LP core init ---- */

static void lp_core_init(void)
{
    ulp_lp_core_cfg_t cfg = {
        .wakeup_source = ULP_LP_CORE_WAKEUP_SOURCE_LP_TIMER,
        .lp_timer_sleep_duration_us = 5 * 1000 * 1000,
    };

    ESP_ERROR_CHECK(ulp_lp_core_load_binary(
        lp_core_main_bin_start,
        (lp_core_main_bin_end - lp_core_main_bin_start)));

    ESP_ERROR_CHECK(ulp_lp_core_run(&cfg));
    ESP_LOGI(TAG, "LP core started (5s timer wakeup)");
}

static void init_lp_uart(void)
{
    lp_core_uart_cfg_t cfg = LP_CORE_UART_DEFAULT_CONFIG();
    cfg.uart_proto_cfg.baud_rate = 9600;
    cfg.uart_pin_cfg.tx_io_num = -1;
    cfg.uart_pin_cfg.rx_io_num = 4;
    ESP_ERROR_CHECK(lp_core_uart_init(&cfg));
    ESP_LOGI(TAG, "LP UART initialized (RX=GPIO4, 9600 baud)");
}

/* ---- DS3231 RTC ---- */

static void init_ds3231(void)
{
    i2c_master_bus_handle_t bus = i2c_bus_get_handle();

    esp_err_t ret = ds3231_probe(bus);
    if (ret != ESP_OK) {
        ESP_LOGW(TAG, "DS3231 not found on I2C bus: %s", esp_err_to_name(ret));
        return;
    }

    ret = ds3231_init(bus, &s_ds3231_dev);
    if (ret != ESP_OK) {
        ESP_LOGE(TAG, "DS3231 init failed: %s", esp_err_to_name(ret));
        return;
    }

    uint32_t epoch = 0;
    ds3231_get_time(s_ds3231_dev, &epoch);
    if (epoch == 0) {
        ESP_LOGW(TAG, "DS3231 time not set — timestamps will be 0 until configured");
    } else {
        ESP_LOGI(TAG, "DS3231 time: epoch %u", (unsigned)epoch);
    }
}

static uint32_t get_epoch(void)
{
    if (!s_ds3231_dev) return 0;
    uint32_t epoch = 0;
    ds3231_get_time(s_ds3231_dev, &epoch);
    return epoch;
}

/* ---- BME280 ---- */

static void init_bme280(void)
{
    i2c_master_bus_handle_t bus = i2c_bus_get_handle();

    esp_err_t ret = bme280_probe(bus);
    if (ret != ESP_OK) {
        ESP_LOGW(TAG, "BME280 not found on I2C bus: %s", esp_err_to_name(ret));
        return;
    }

    ret = bme280_init(bus, &s_bme280_dev);
    if (ret != ESP_OK) {
        ESP_LOGE(TAG, "BME280 init failed: %s", esp_err_to_name(ret));
        return;
    }

    bme280_data_t data;
    ret = bme280_read(s_bme280_dev, &data);
    if (ret == ESP_OK) {
        ESP_LOGI(TAG, "BME280 test read: %.2f°C, %.1f hPa, %u%% RH",
                 data.temp_c_x100 / 100.0,
                 data.press_hpa_x10 / 10.0,
                 data.rh_pct);
    }
}

/* ---- OLED ---- */

static void init_oled(void)
{
    i2c_master_bus_handle_t bus = i2c_bus_get_handle();

    esp_err_t ret = oled_probe(bus);
    if (ret != ESP_OK) {
        ESP_LOGW(TAG, "OLED not found on I2C bus: %s", esp_err_to_name(ret));
        return;
    }

    ret = oled_init(bus, &s_oled_dev);
    if (ret != ESP_OK) {
        ESP_LOGE(TAG, "OLED init failed: %s", esp_err_to_name(ret));
        return;
    }

    /* Display is ON after oled_init() — leave it on, UI will use it immediately */
}

/* ---- LP core shared memory access ----
 *
 * The LP core defines a packed wind_sample_t (5 bytes: u16 + u16 + u8).
 * 12 packed samples = 60 bytes = 15 uint32_t words = ulp_sample_buffer[15].
 * Main core must use a matching packed struct to read the raw bytes correctly.
 */

typedef struct {
    uint16_t speed_mps_x10;
    uint16_t direction_deg;
    uint8_t  valid;
} __attribute__((packed)) lp_wind_sample_t;

/* ---- Sample flush ---- */

static void flush_samples_to_sd(void)
{
    uint16_t rain_adc = read_rain_adc();
    ESP_LOGI(TAG, "Rain ADC raw: %u", rain_adc);

    uint32_t epoch = get_epoch();
    if (epoch == 0) {
        ESP_LOGW(TAG, "DS3231 time not set — using 0 epoch");
    }

    ESP_LOGI(TAG, "Flushing samples to SD card (epoch=%u)", (unsigned)epoch);

    esp_err_t ret = storage_init();
    if (ret != ESP_OK) {
        ESP_LOGE(TAG, "SD card init failed: %s", esp_err_to_name(ret));
        return;
    }

    bme280_data_t env_data = {0};
    if (s_bme280_dev) {
        esp_err_t bret = bme280_read(s_bme280_dev, &env_data);
        if (bret != ESP_OK) {
            ESP_LOGW(TAG, "BME280 read failed: %s", esp_err_to_name(bret));
        } else {
            ESP_LOGI(TAG, "BME280: %.2f°C, %.1f hPa, %u%% RH",
                     env_data.temp_c_x100 / 100.0,
                     env_data.press_hpa_x10 / 10.0,
                     env_data.rh_pct);
        }
    }

    ret = storage_write_env_sample(epoch,
                                   env_data.temp_c_x100,
                                   env_data.rh_pct,
                                   env_data.press_hpa_x10);
    if (ret != ESP_OK) {
        ESP_LOGE(TAG, "Failed to write env sample: %s", esp_err_to_name(ret));
    }

    /* Read wind samples from LP core shared memory.
     * ulp_sample_buffer is 15 uint32_t words = 60 bytes = 12 packed samples.
     * ulp_sample_count is the number of valid samples (0-12).
     * ulp_buffer_ready is set by LP core when buffer is full. */
    uint16_t lp_count = (uint16_t)ulp_sample_count;
    if (lp_count > 0 && lp_count <= 12) {
        const lp_wind_sample_t *lp_samples = (const lp_wind_sample_t *)ulp_sample_buffer;

        /* Convert packed LP struct to storage struct (field-by-field, no padding issues) */
        storage_wind_sample_t storage_samples[12];
        int valid_count = 0;
        for (int i = 0; i < lp_count; i++) {
            if (lp_samples[i].valid) {
                storage_samples[valid_count].speed_mps_x10 = lp_samples[i].speed_mps_x10;
                storage_samples[valid_count].direction_deg = lp_samples[i].direction_deg;
                storage_samples[valid_count].valid = 1;
                valid_count++;
            }
        }

        if (valid_count > 0) {
            ESP_LOGI(TAG, "Writing %d wind samples to SD (of %d LP samples)",
                     valid_count, lp_count);
            ret = storage_write_wind_samples(epoch, storage_samples, valid_count, rain_adc);
            if (ret != ESP_OK) {
                ESP_LOGE(TAG, "Failed to write wind samples: %s", esp_err_to_name(ret));
            }
        } else {
            ESP_LOGW(TAG, "No valid wind samples in LP buffer (count=%u)", lp_count);
        }

        /* Signal LP core that buffer has been consumed */
        ulp_buffer_ready = 0;
    } else if (lp_count == 0) {
        ESP_LOGD(TAG, "No wind samples in LP buffer");
    } else {
        ESP_LOGW(TAG, "LP sample count out of range: %u", lp_count);
    }

    storage_deinit();
    ESP_LOGI(TAG, "SD card flush complete");
}

/* ---- Interactive UI mode ---- */

static void handle_con_button(void)
{
    ESP_LOGI(TAG, "CON button pressed — entering interactive UI");

    /* Power on OLED via MOSFET before initializing it.
     * The MOSFET gate has a 10k pull-up so OLED is OFF during sleep. */
    gpio_config_t mosfet_cfg = {
        .pin_bit_mask = (1ULL << OLED_MOSFET_GPIO),
        .mode = GPIO_MODE_OUTPUT,
        .pull_up_en = GPIO_PULLUP_ENABLE,
        .pull_down_en = GPIO_PULLDOWN_DISABLE,
        .intr_type = GPIO_INTR_DISABLE,
    };
    gpio_config(&mosfet_cfg);
    gpio_set_level(OLED_MOSFET_GPIO, 0);  /* LOW = MOSFET on */
    vTaskDelay(pdMS_TO_TICKS(50));  /* OLED power-up time */

    /* Init OLED now that it has power */
    init_oled();
    if (!s_oled_dev) {
        ESP_LOGE(TAG, "OLED init failed — cannot start UI");
        gpio_set_level(OLED_MOSFET_GPIO, 1);  /* Power off OLED */
        return;
    }

    /* Run UI — blocks until user selects Sleep/Halt or auto-sleep timeout */
    esp_err_t result = ui_run(s_oled_dev, s_ds3231_dev, s_bme280_dev);

    if (result == ESP_ERR_INVALID_STATE) {
        /* Halt requested — stop everything, enter permanent deep sleep.
         * Power cycle is the only way out. */
        ESP_LOGI(TAG, "Halt requested — stopping LP core and entering permanent deep sleep");

        /* Stop the LP core so it stops triggering ULP wakeups */
        ulp_lp_core_stop();

        /* Disable ALL wakeup sources — no button, no timer, no ULP */
        esp_sleep_disable_wakeup_source(ESP_SLEEP_WAKEUP_ULP);
        esp_sleep_disable_wakeup_source(ESP_SLEEP_WAKEUP_TIMER);
        esp_sleep_disable_wakeup_source(ESP_SLEEP_WAKEUP_GPIO);

        /* Enter deep sleep — nothing can wake us except power cycle */
        esp_deep_sleep_start();
        /* esp_deep_sleep_start() does not return */
    }

    /* Normal sleep — fall through to deep sleep with all wakeup sources */
}

/* Wait for CON button to be released before sleeping.
 * Prevents immediate re-wakeup if user holds the button too long. */
static void wait_for_con_release(void)
{
    while (gpio_get_level(CON_BUTTON_GPIO) == 0) {
        vTaskDelay(pdMS_TO_TICKS(10));
    }
}

/* ---- Main ---- */

void app_main(void)
{
    /* Set timezone to UTC so mktime() produces correct epoch values.
     * Without this, mktime() applies system TZ which defaults to UTC
     * but could be changed by SNTP or setenv elsewhere. */
    setenv("TZ", "UTC0", 1);
    tzset();

    uint32_t wakeup_causes = esp_sleep_get_wakeup_causes();

    /* I2C bus + sensors + ADC lose state in deep sleep (CPU reset on wake).
     * Must re-init on every wake, not just cold boot. */
    i2c_bus_init();
    init_ds3231();
    init_bme280();
    init_rain_adc();

    if (wakeup_causes == 0) {
        /* Cold boot — init LP core + UART (only once; LP core persists across deep sleep) */
        ESP_LOGI(TAG, "Cold boot — initializing");
        init_lp_uart();
        lp_core_init();

        /* Configure GPIO22 (CON) as wakeup source — active low (falling edge) */
        gpio_set_direction(CON_BUTTON_GPIO, GPIO_MODE_INPUT);
        gpio_pullup_en(CON_BUTTON_GPIO);
        gpio_wakeup_enable(CON_BUTTON_GPIO, GPIO_INTR_LOW_LEVEL);

    } else if (wakeup_causes & BIT(ESP_SLEEP_WAKEUP_ULP)) {
        ESP_LOGI(TAG, "Woken by LP core");
        flush_samples_to_sd();

    } else if (wakeup_causes & BIT(ESP_SLEEP_WAKEUP_GPIO)) {
        ESP_LOGI(TAG, "Woken by CON button");
        handle_con_button();
    }

    /* Wait for CON button to be released before sleeping (GPIO wake only).
     * Prevents immediate re-wakeup if user holds the button too long. */
    if (wakeup_causes & BIT(ESP_SLEEP_WAKEUP_GPIO)) {
        wait_for_con_release();
    }

    /* Enable wakeup sources for next sleep cycle */
    esp_sleep_enable_ulp_wakeup();
    esp_sleep_enable_gpio_wakeup();
    esp_sleep_enable_timer_wakeup(MAIN_WAKE_INTERVAL_US);

    ESP_LOGI(TAG, "Entering deep sleep");
    esp_deep_sleep_start();
}

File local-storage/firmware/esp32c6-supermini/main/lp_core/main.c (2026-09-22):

/*
 * WeatherNerd ESP32-C6 — LP Core firmware
 *
 * Runs on the ULP LP Core (RISC-V coprocessor) while the main core sleeps.
 * Wakes every 5 seconds via LP timer and performs:
 *
 * 1. Trigger WindNerd Core (GPIO1 pulse → STM32G031F8 wakes from STOP mode)
 * 2. Read UART response on LP_UART (GPIO4, 9600 baud) — "WNI,<speed>,<dir>\n"
 * 3. Store wind sample in shared memory buffer
 * 4. After 12 samples (1 minute), wake the main core to flush to SD card
 *
 * Note: The ESP32-C6 LP core does not have LP ADC support.
 * Rain ADC sampling is handled by the main core on its 1-minute wake cycle.
 *
 * ADC and UART are initialized by the main core before starting the LP core.
 * The LP core only reads from them.
 */

#include <stdint.h>
#include <string.h>
#include "ulp_lp_core.h"
#include "ulp_lp_core_utils.h"
#include "ulp_lp_core_gpio.h"
#include "ulp_lp_core_uart.h"
#include "ulp_lp_core_print.h"

/* ---- Configuration ---- */

#define SAMPLES_PER_FLUSH       12      /* 12 × 5s = 60s = 1 min */
#define WINDNERD_TRIGGER_PIN   LP_IO_NUM_1
#define LP_UART_PORT            LP_UART_NUM_0

#define UART_BUF_SIZE           64
#define UART_TIMEOUT_MS         100

/* ---- Shared variables (accessible from main core via ulp_ prefix) ---- */

typedef struct {
    uint16_t speed_mps_x10;    /* wind speed × 10 (3.2 m/s = 32) */
    uint16_t direction_deg;    /* 0-359, or 0 if read failed */
    uint8_t  valid;            /* 1 = valid sample, 0 = empty */
} __attribute__((packed)) wind_sample_t;

/* These globals are exported to the main core via the generated header. */
wind_sample_t sample_buffer[SAMPLES_PER_FLUSH];
uint16_t sample_write_idx;
uint16_t sample_count;
uint8_t  buffer_ready;  /* Set by LP core when buffer is full, cleared by main core */

/* ---- WindNerd trigger ---- */

static void trigger_windnerd(void)
{
    /* Pulse GPIO1 high for 10ms to wake the STM32G031F8 from STOP mode.
     * The STM32 is configured for EXTI RISING on its trigger pin. */
    ulp_lp_core_gpio_set_level(WINDNERD_TRIGGER_PIN, 1);
    ulp_lp_core_delay_us(10 * 1000);
    ulp_lp_core_gpio_set_level(WINDNERD_TRIGGER_PIN, 0);
}

/* ---- UART parsing ---- */

/* Parse "WNI,<speed>,<dir>\n" from UART buffer.
 * Returns 0 on success, -1 on parse failure. */
static int parse_wni(const char *buf, int len, uint16_t *speed_x10, uint16_t *direction)
{
    const char *p = NULL;
    for (int i = 0; i <= len - 4; i++) {
        if (buf[i] == 'W' && buf[i+1] == 'N' && buf[i+2] == 'I' && buf[i+3] == ',') {
            p = &buf[i + 4];
            break;
        }
    }
    if (!p) return -1;

    /* Parse speed (float × 10) */
    int speed_int = 0, speed_frac = 0;
    const char *s = p;
    while (*s >= '0' && *s <= '9') {
        speed_int = speed_int * 10 + (*s - '0');
        s++;
    }
    if (*s == '.') {
        s++;
        if (*s >= '0' && *s <= '9') {
            speed_frac = *s - '0';
            s++;
        }
    }
    *speed_x10 = speed_int * 10 + speed_frac;

    if (*s != ',') return -1;
    s++;

    /* Parse direction (integer 0-359) */
    int dir = 0;
    while (*s >= '0' && *s <= '9') {
        dir = dir * 10 + (*s - '0');
        s++;
    }
    if (dir < 0 || dir > 359) dir = 0;
    *direction = dir;

    return 0;
}

/* ---- Main ---- */

int main(void)
{
    /* Initialize trigger GPIO — UART is already initialized
     * by the main core before starting the LP core. */
    ulp_lp_core_gpio_init(WINDNERD_TRIGGER_PIN);
    ulp_lp_core_gpio_output_enable(WINDNERD_TRIGGER_PIN);
    ulp_lp_core_gpio_set_level(WINDNERD_TRIGGER_PIN, 0);

    char uart_buf[UART_BUF_SIZE];

    while (1) {
        /* 1. Trigger WindNerd */
        trigger_windnerd();

        /* 2. Read UART response */
        memset(uart_buf, 0, sizeof(uart_buf));
        int len = lp_core_uart_read_bytes(LP_UART_PORT, (uint8_t *)uart_buf,
                                          sizeof(uart_buf) - 1, UART_TIMEOUT_MS);

        /* 3. Parse and store sample */
        wind_sample_t *slot = &sample_buffer[sample_write_idx];
        slot->valid = 0;

        if (len > 0) {
            uint16_t speed_x10 = 0, direction = 0;
            if (parse_wni(uart_buf, len, &speed_x10, &direction) == 0) {
                slot->speed_mps_x10 = speed_x10;
                slot->direction_deg = direction;
                slot->valid = 1;
            }
        }

        /* 4. Advance buffer */
        sample_write_idx = (sample_write_idx + 1) % SAMPLES_PER_FLUSH;
        if (sample_count < SAMPLES_PER_FLUSH) {
            sample_count++;
        }

        /* 5. After 12 samples, wake the main core.
         * Set buffer_ready so main core knows data is available.
         * Wait for main core to clear it before overwriting (race condition prevention). */
        if (sample_write_idx == 0 && sample_count == SAMPLES_PER_FLUSH) {
            buffer_ready = 1;
            ulp_lp_core_wakeup_main_processor();
        }

        /* 6. If buffer was consumed by main core, reset for next cycle.
         * This check happens at the top of the next 5s loop iteration —
         * by then the main core has had plenty of time to read the buffer. */
        if (buffer_ready == 0 && sample_count == SAMPLES_PER_FLUSH) {
            sample_count = 0;
            sample_write_idx = 0;
        }

        /* 7. Halt — LP timer will wake us in 5 seconds */
        ulp_lp_core_halt();
    }

    return 0;
}

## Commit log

2026-09-22 initial notes on weathernerd - the windnerd-core "companion" / expansion / whatever that adds more sensors. starting with long-term local-storage datalogging
2026-09-22 explain why we use spi vs sdio for sdcard
2026-09-22 firmware build for STM32G031F8Px
2026-09-22 skeleton esp32c6 firmware
2026-09-22 esp32c6 firmware more fleshed out
    [partitions.csv, weathernerd-hub.kicad_pcb, weathernerd-hub.kicad_sch]
2026-09-22 ### Critical fixes
    **1. I2C bus + sensors not re-initialized after deep sleep wake**
    - Moved `i2c_bus_init()`, `init_ds3231()`, `init_bme280()`, `init_rain_adc()` to run on **every** wake (cold boot + ULP + GPIO), not just cold boot
    - Only LP UART + LP core init remain cold-boot-only (LP core persists across deep sleep)
    - OLED init moved to `handle_con_button()` (only needed on GPIO wake, after MOSFET power-on)
    - `s_oled_dev` is now populated on every GPIO wake before `ui_run()` is called
    **2. CSV header never written for new files**
    - `ensure_header()` now writes the header when `stat()` fails (file doesn't exist) instead of returning early
    - Creates the file with `fopen("w")`, writes head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
    [bme280.c, ds3231.c, main.c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]
2026-09-22 Wind samples → SD card (ulp_ variable access)
2026-09-24 kicad stuff
2026-09-24 fix pin locations
2026-09-24 no uuids on props
2026-09-24 kicad10 for footprint too
2026-09-24 some schematic progress
    [weathernerd-hub.kicad_pcb, weathernerd-hub.kicad_sch]
2026-09-25 fix pcb starting point
    [weathernerd-hub.kicad_pcb]
2026-09-25 the start of a human touch
    [weathernerd-hub.kicad_pcb, weathernerd-hub.kicad_sch]
2026-09-28 add MCP23008 and SIM7080G info
    [weathernerd-hub.kicad_sch]
2026-09-28 fix sch too
    [weathernerd-hub.kicad_sch]

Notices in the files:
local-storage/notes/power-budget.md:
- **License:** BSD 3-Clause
